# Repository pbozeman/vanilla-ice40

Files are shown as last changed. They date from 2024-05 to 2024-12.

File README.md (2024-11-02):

# Vanilla ICE40

Hardware design and verilog sample files for Lattice ICE40
development boards and expansion boards.

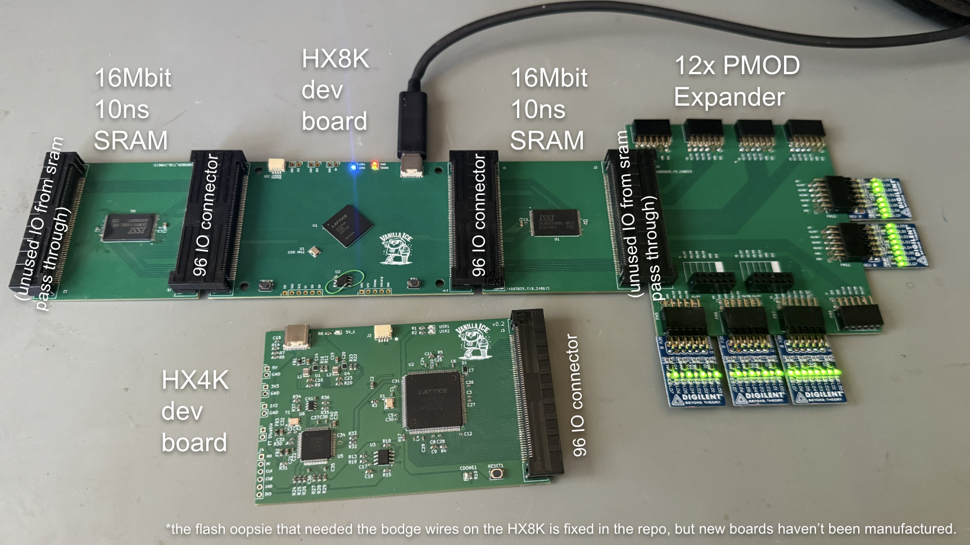
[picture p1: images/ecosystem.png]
Vanilla ICE40 ecosystem vanilla ice40 ecosystem


## Development Boards

There are 2 core boards, one based on an ICE40 HX4K with 96
available IO pins, and another based on an ICE40 HX8K with
192 available IO pins.

The core boards are "vanilla" with minimal on board peripherals.
Almost all IO pins are routed to mezzanine connectors. Expansion
boards can be mixed and matched for different projects, while reusing
the core board. The expansion boards can be daisy chained.

This is a work in progress for use in a personal project, but so far
the following boards are in the repo:

* **vanilla-ice40**: core board based on the HX4K TQ144 package. There is
an onboard USBC connector for power, programming, and uart/com port
communication. It is directly programmable with Lattice Diamond Programmer
and icestorm. The onboard FTDI chip can be disabled. The SPI pins to the
flash and ice40 are exposed if one wishes to use an external
programmer. There are 2 onboard user LEDs, 1 I2C connector, and 96 IOs
routed to a mezzanine connector on the right side of the board.

* **vanilla-ice40-hx8k**: core board based on the HX8K CT256 BGA package.
It is similar to the board above, but ads a user button on board. It has
192 available IO pins, with 96 IO pins routed to the left and 96 pins routed
to the right of the board. (A PCF file is provided for both boards, sharing
the same signal names for the right side of the board.)

* **breakout-sram**: 16Mbit sram chip with with mezzanine connectors
on both side of the board for pass through of unused pins.

* **breakout-pmod**: 12 port pmod connector, spaced such that they
can be used in single, dual or quad pmod configurations.

* **breakout-passthrough**: direct passthrough of all signals. (This
is basically a template and for testing.) NOTE: the net names and
labels on this board are stale.

Parts numbers are populated for Digikey and JLCPCB, and JLCPCB
rotations are provided. The bom and positions file, along with
gerbers, can be exported with the JLCPCB Fabrication Toolkit
plugin.

All boards other than the HX8K are single sided and optimized for cost
and hand assembly. My soldering skills are below average, and I manged to
hand assemble versions of each of these these boards other than the HX8K.
The HX8K uses BGA, via-in-pad, and 201 sized caps between the BGA pads, and
likely requires higher soldering skills.

## Verilog examples

Basic verilog examples. Icecube2 projects exist in lattice_proj.

Test benches run under iverilog by running `make check` to run
all test benches. Wave files are written
to `.build/<test_name>.vcd` and can be viewed with gtkwave.

Diamond Programmer does not use relative paths, so programmer
projects are not checked in.

### NOTE

I have been doing all recent development icestorm toolchain, so the Icecube2
projects are stale. I have heard that yosys/nextprn don't scale to larger designs,
but for now, they are able to complete synthesis and place-and-route for all
the examples before Icecube2 can synthesize a single project. That coupled with
the ability to compile and program from the command line is so delightful compared
to Icecube2.

## Makefile Targets

The Makefile in the rtl dir works for both hx4k and hx8k boards, but
one needs to change the DEVICE and PACKAGE at the top of the file based on
the board in use.

* **unit**: runs unit tests for any changed files. This is the default
target if one is not specified. vcd files are written to .build/\<name\>_tb.vcd

* **list**: provides a listing of unit test and programming targets

* **\<name\>_tb**: runs the test bench named 'name'

* **\<name\>_top**: builds the bitstream for 'name' and programs the attached board
with the bitstream.

* **lint**: runs verilator on all _tb files and their includes.

* **format**: runs verible source code formatter on all verilog files.

* **check**: runs linter and full unit test suite, even if files have not changed.

* **bits**: build bitstreams for all top level files.

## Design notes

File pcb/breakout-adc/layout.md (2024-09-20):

# Breakout ADC Layout Notes

## General notes

The board is (mostly) optimized for single sided assembly.
This is to keep costs down if using getting PCB assembly
service, or to avoid needing 2 stencils for DIY stencil based
soldering. This turned out to not be possible due to the
place and routing requirements of the op amps, but the
components on the backside were kept to a minimum and should
be easily and quickly hand soldered.

## Op Amp

[lmh6551 data sheet](https://www.ti.com/lit/ds/symlink/lmh6551.pdf)

### Power and GND plane guidelines

The following quote implies that there should be a ground plane
one layer 1 for the caps to connect directly to.

>
>The SMT capacitors should be connected directly to a ground plane.
>Thin traces or small vias will reduce the effectiveness of bypass
>capacitors.

Does this quote only apply to layer1, or does it apply to the
layers below as well?

>The LMH6551 is sensitive to parasitic capacitances on the amplifier
>inputs and to a lesser extent on the outputs as well. Ground and
>power plane metal should be removed from beneath the amplifier
>and from beneath Rf and Rg.

The 2 requirements above seem impossible to satisfy with all the
components on the top of the board. I gave up on optimizing
for single sided assembly and put the feedback network and
components on the bottom of the board. Note: the reference
design has the feedback network on the opposite side of the
chip as well.

Note: there is a power trace run under Rf, that goes under a large
percentage of the pad, but there is in the reference layout also.

## ADC

[ADC10DL065 data sheet](https://www.ti.com/lit/ds/symlink/adc10dl065.pdf)

### V reference pins

VRPA/B, VRMA/B, VMRNA/B should all share a single ground connection.
See figure 7 in the data sheet.

### DRGND

Regarding the following quote, is it ok to have a GND plane on layer 2
and then just drop a via to it as long as that via is moved a bit away
from the chip? It does seem to imply that layer1 should not have a gnd
plane around the chip and that everyone should be dropping down to the
layer below? Or, should I handle the GND for these pins as a different
net in the schematic and then run a trace away from the chip and connect
it to the main gnd with something acting as a net-tie?

>
>The ground return for the data outputs (DR GND) carries the ground current
>for the output drivers. The output current can exhibit high transients that
>could add noise to the conversion process. To prevent this from happening,
>the DR GND pins should NOT be connected to system ground in close proximity
>to any of the ADC10DL065’s other ground pins.

Confirm this was the correct routing: I ended up running the gnd vias for
DRGND outside the quiet area.

### Digital output pins
>
>The effects of the noise generated from the ADC output switching can be
>minimized through the use of 100Ω resistors in series with each data output
>line. Locate these resistors as close to the ADC output pins as possible.

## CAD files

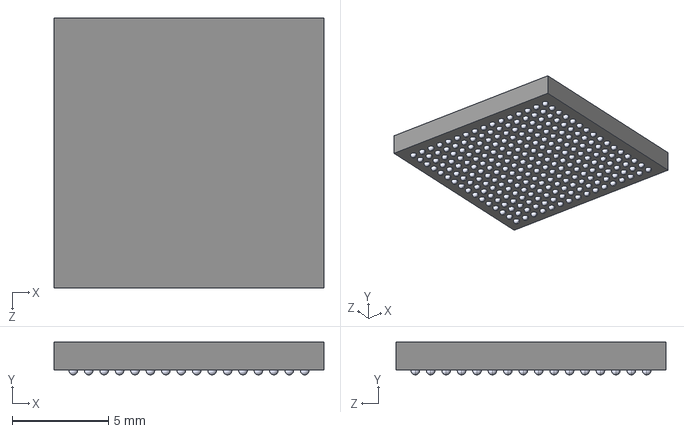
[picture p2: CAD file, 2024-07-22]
pcb/models/ICE40HX8K-CT256/ICE40HX8K-CT256.step
14.0 x 1.70 x 14.0 mm

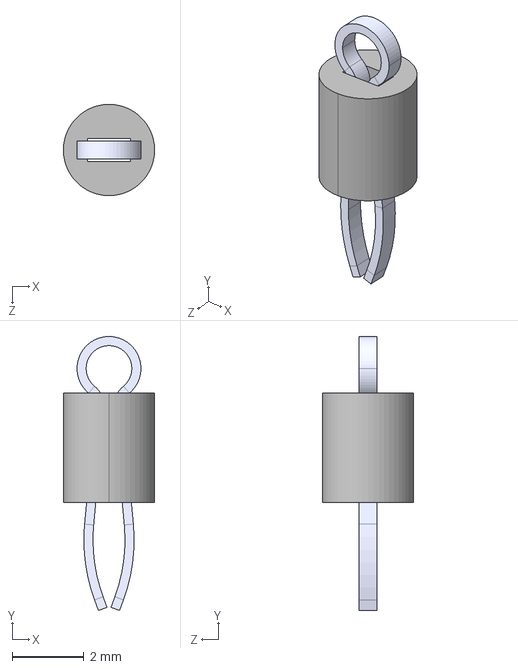
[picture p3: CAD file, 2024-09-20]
pcb/models/keystone/5118.step
2.54 x 7.62 x 2.54 mm

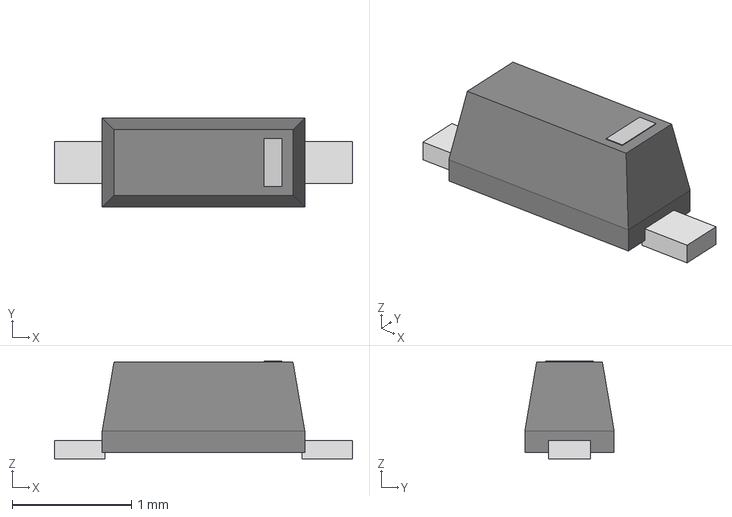
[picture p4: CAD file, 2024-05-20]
pcb/models/ul_1N4448WSF-7/SOD323F_DIO.step
2.50 x 0.75 x 0.819 mm

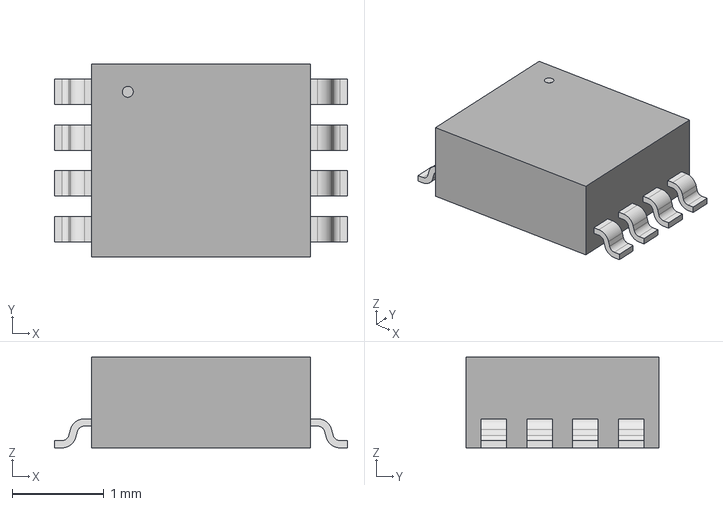
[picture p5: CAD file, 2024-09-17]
pcb/models/ul_74AVC9112DCH/VSSOP8_SOT765-1_NEX.step
3.20 x 2.11 x 0.993 mm

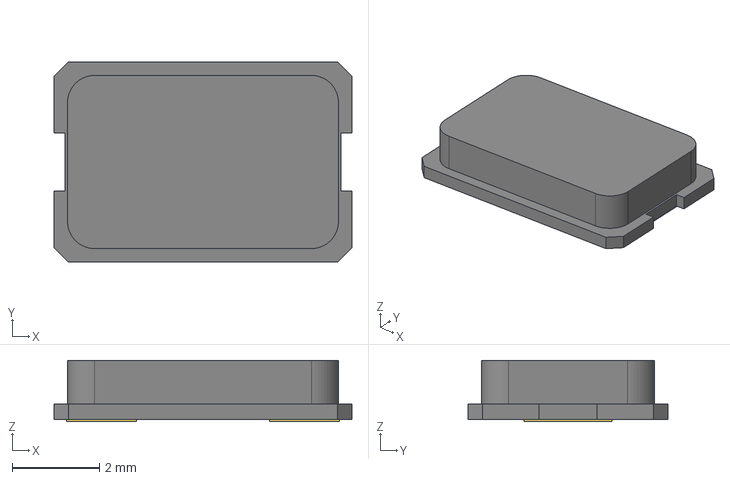
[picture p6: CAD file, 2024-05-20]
pcb/models/ul_ABM7-12-000MHZ-B4-T/XTAL_ABM7_ABR.step
6.82 x 4.58 x 1.40 mm

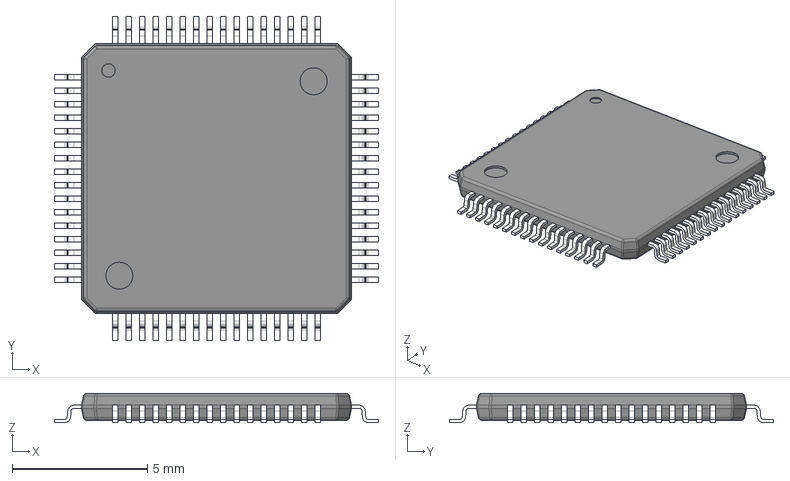
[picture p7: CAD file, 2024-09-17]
pcb/models/ul_ADC10DL065CIVS-NOPB/PAG0064A.stp
12.0 x 12.0 x 1.09 mm
BODY_VEC64A
LEAD_VEC64A x 64

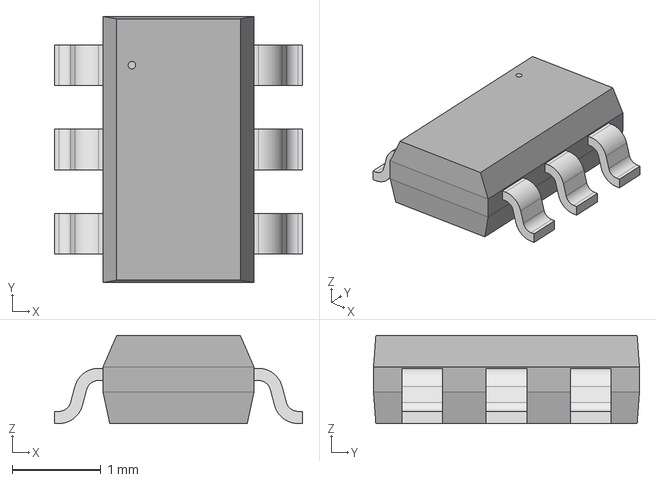
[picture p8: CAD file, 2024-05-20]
pcb/models/ul_AP63300WU-7/TSOT6_AP63300WU-7_DIO.step
2.80 x 3.00 x 0.993 mm

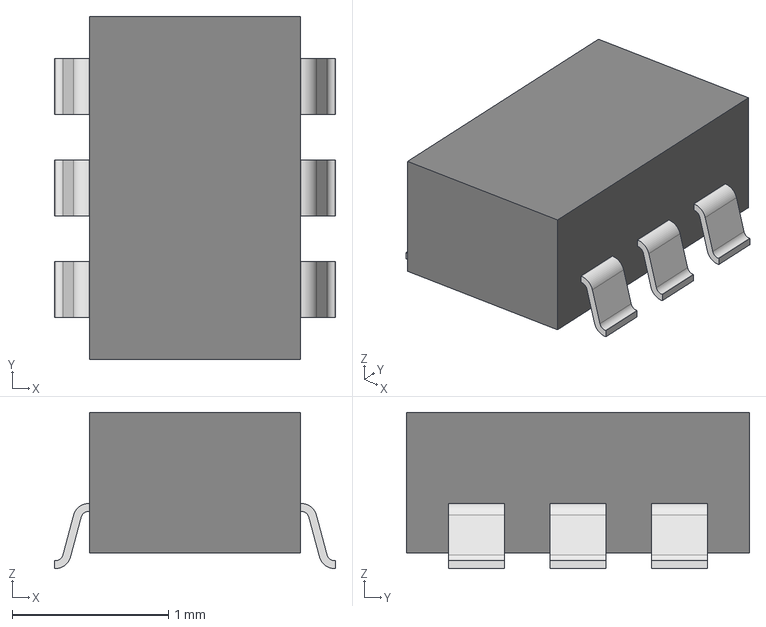
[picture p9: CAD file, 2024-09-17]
pcb/models/ul_D1213A-04S-7/SOT-363_DIO.step
1.80 x 2.20 x 1.00 mm

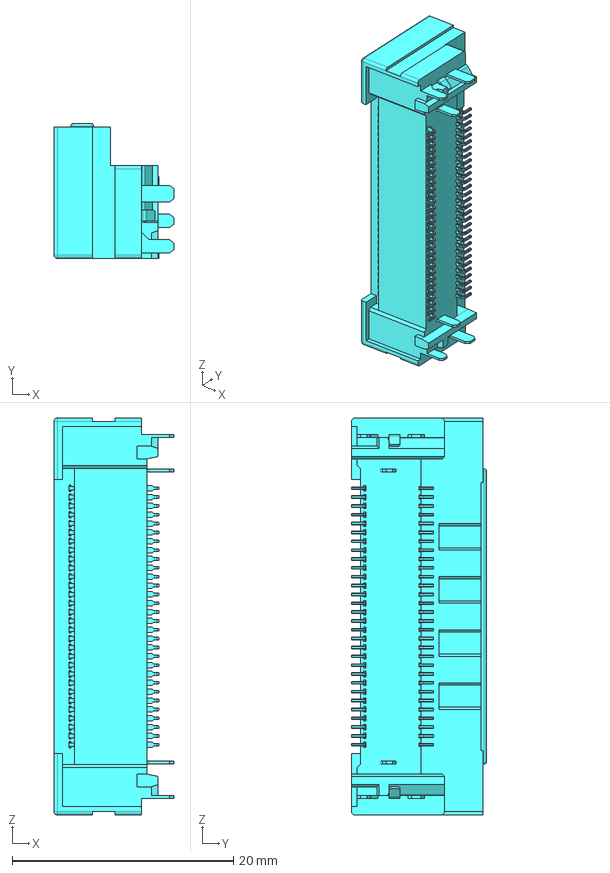
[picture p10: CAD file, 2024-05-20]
pcb/models/ul_FX18-60S-0-8SH/FX18-60S-0.8SH--3DModel-STEP-1.STEP
10.9 x 12.2 x 35.9 mm

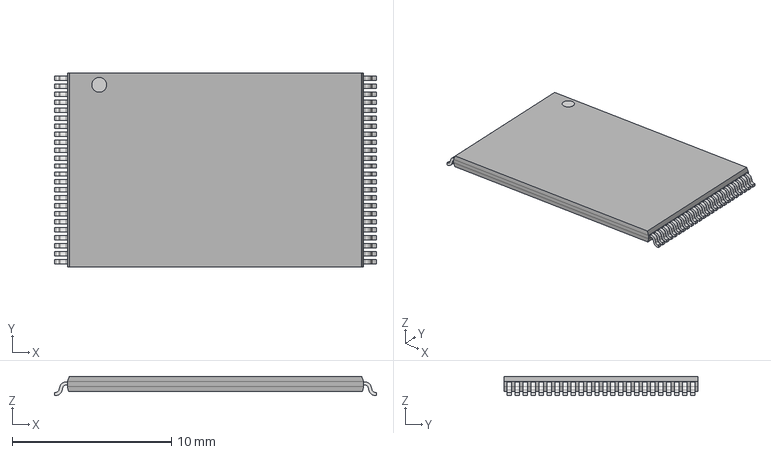
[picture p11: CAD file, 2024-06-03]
pcb/models/ul_IS61WV102416DBLL-10TLI/IS61WV102416DBLL-10TLI_ISI.step
20.2 x 12.2 x 1.20 mm

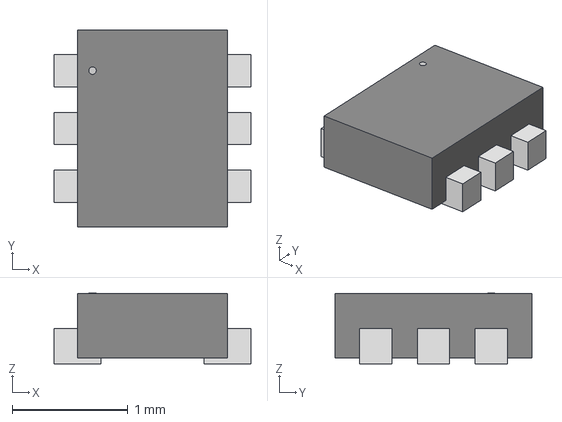
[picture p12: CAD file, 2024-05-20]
pcb/models/ul_TPS563252DRLR/SOT6_DRL_TEX.step
1.70 x 1.70 x 0.612 mm

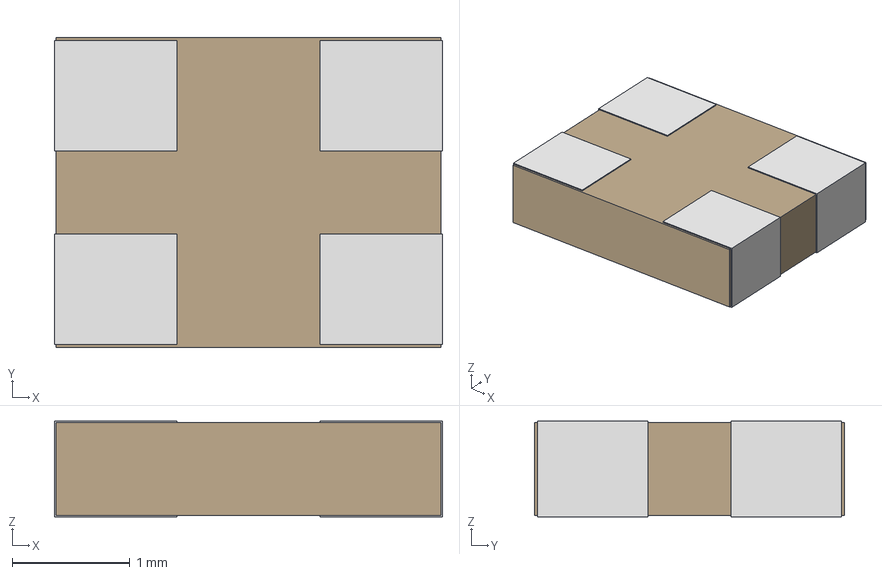
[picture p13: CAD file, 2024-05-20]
pcb/models/ul_X322512MSB4SI/SMD_2MSB4SI_YXC.step
3.30 x 2.64 x 0.813 mm

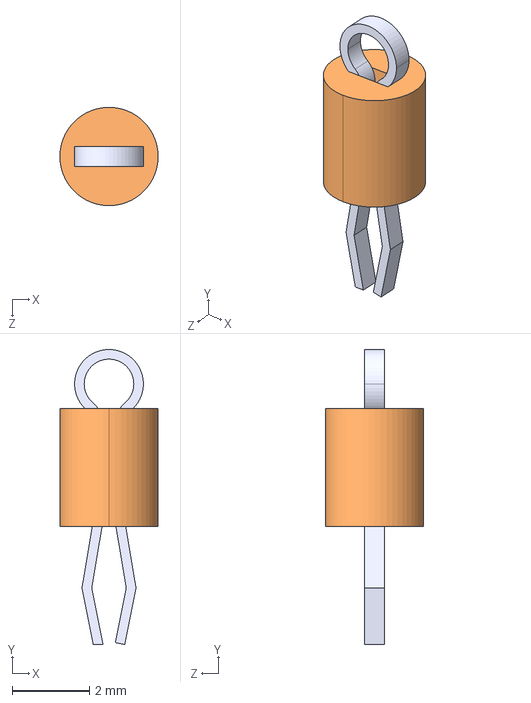
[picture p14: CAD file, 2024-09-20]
pcb/models/keystone/5003.step
2.54 x 7.62 x 2.54 mm

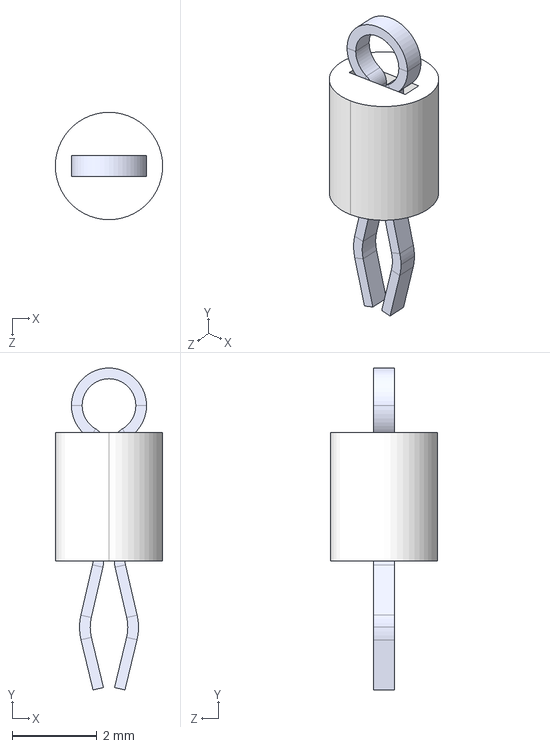
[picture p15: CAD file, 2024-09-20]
pcb/models/keystone/5002.step
2.54 x 7.62 x 2.54 mm

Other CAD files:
pcb/models/keystone/5001.step
pcb/models/keystone/5115.step
pcb/models/keystone/5116.step
pcb/models/keystone/5117.step
pcb/models/keystone/5000.step
pcb/models/keystone/5004.step
pcb/models/keystone/5119.step

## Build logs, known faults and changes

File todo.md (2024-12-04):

# Todo and fixes

## PCB

### All

- consider redoing the pins on the P b2b connector to match S.
- audit and standardize R manufacturer. Used to be bournes,
  but the need for 0.1% tolerance from the same vendor at both
  digikey and lcsc meant using Yaego. (Not that multivendor is
  bad, but I find single vendor to be more ascetically pleasing :)

### Main board

- lcsc green led is a bit dim
- validate i2c
- validate urx/utx
- validate all passive silk screen positions
- bump font sizes
- remove 3v3 and 1v2 voltage breakouts
- consider signal only option to use ice boards together
- should OE enable on the oscillator use a 1K+ resistor instead of 0R?
- move the resistors for the LEDs to the top of the board. They made good
  test points, and testing at the led doesn't work as well.

### ADC board

- X1 is a default kicad symbol and footprint. I added a pin 1 marker, but
  accidentally did so to the system footprint. Duplicate the symbol as a custom
  symbol and fix the datasheet and footprint correctly.

### PMOD board

- make font bigger
- move pmods slightly over the edge of the pcb
- add mounting holes

### Pass through

- update with current board tolerances and sizes (e.g. vias are off)

### SRAM

- add mounting holes
- lower pcb fence vias violate drc tolerances

## RTL

### Project structure

- start moving modules into groups directories in lib
- move unit tests with the lib
- add some sort of check for required parameters to ensure they are set.
  Removing defaults is not an option because icecube2 requires them.

### make

- make: all files are included in both yosys and verification.. limit them to just
  the dependencies
- move to per top pcf files
- there are some assumptions of running from the rtl/examples dir, e.g.
  the pcf gen rules. update the makefile to be cwd agnostic
- consider removing pcf files from being committed to the repo

### misc

- make sure all components have a reset_i
- create reset component and use in top modules

### uart

- add tests

### SRAM

change the sram data and addr ports to use _bus and/or differentiate the caller ports from the
io on the board

### SRAM VGA

- don't read memory during the blanking period
- use vga_pixel_addr, or at least the counter module. There was a wrapping
  error in the manual iteration that wouldn't have happened if these were used.

### axi

- add a tb for axi_sram_dbuf_controller
- data signals are not always multiple of 8 bit values in these designs. Decide if
  this is an issue or not.
- rename axi modules to bla_axi instead of axi_bla, with the exception of modules
  that specifically do axi managment like the axi_2x2
- use the tnx_done detector to track handshakes, especially when needing to
  combine A and W which may not happen at the same time

### adc vga

- use double buffering. Even 800x600 doesn't work with a single sram because
it's running at a 40mhz pixel clock and is trying to share an sram module that
takes 2 clocks per op to complete due to setup and hold times. That means we
are effectively writting/reading at 50mhz. When there is a reader and writer both contending for the sram, the bw of both is reduce to 25mhz, making 640x480 the
max we can do. Double buffering will bring this up to 50mhz, which is enough
for 800x600's 40mhz. 1024x768 will need pipelining/interleaving on top of this.

### gfx

- use axi like interface with valid/ready inputs and valid/ready/last outputs

### Style

- move to system verilog, but decide on what conventions to use
- rename _controller to_ctrl
- use initial_reset in top modules
- use TICK in unit tests
- use ASSERT_EQ in unit tests where applicable
- switch to axi stream for flow control in relevant modules
- move to standardized module instantiation names
- decide on standardize _WIDTH/BITS parameter names
- there is a mix of usage of state, current_state. pick one
- pick if next_ goes at the front or the end
- put _io_ in the port names of wires on the board
- use .signal() for unused signals

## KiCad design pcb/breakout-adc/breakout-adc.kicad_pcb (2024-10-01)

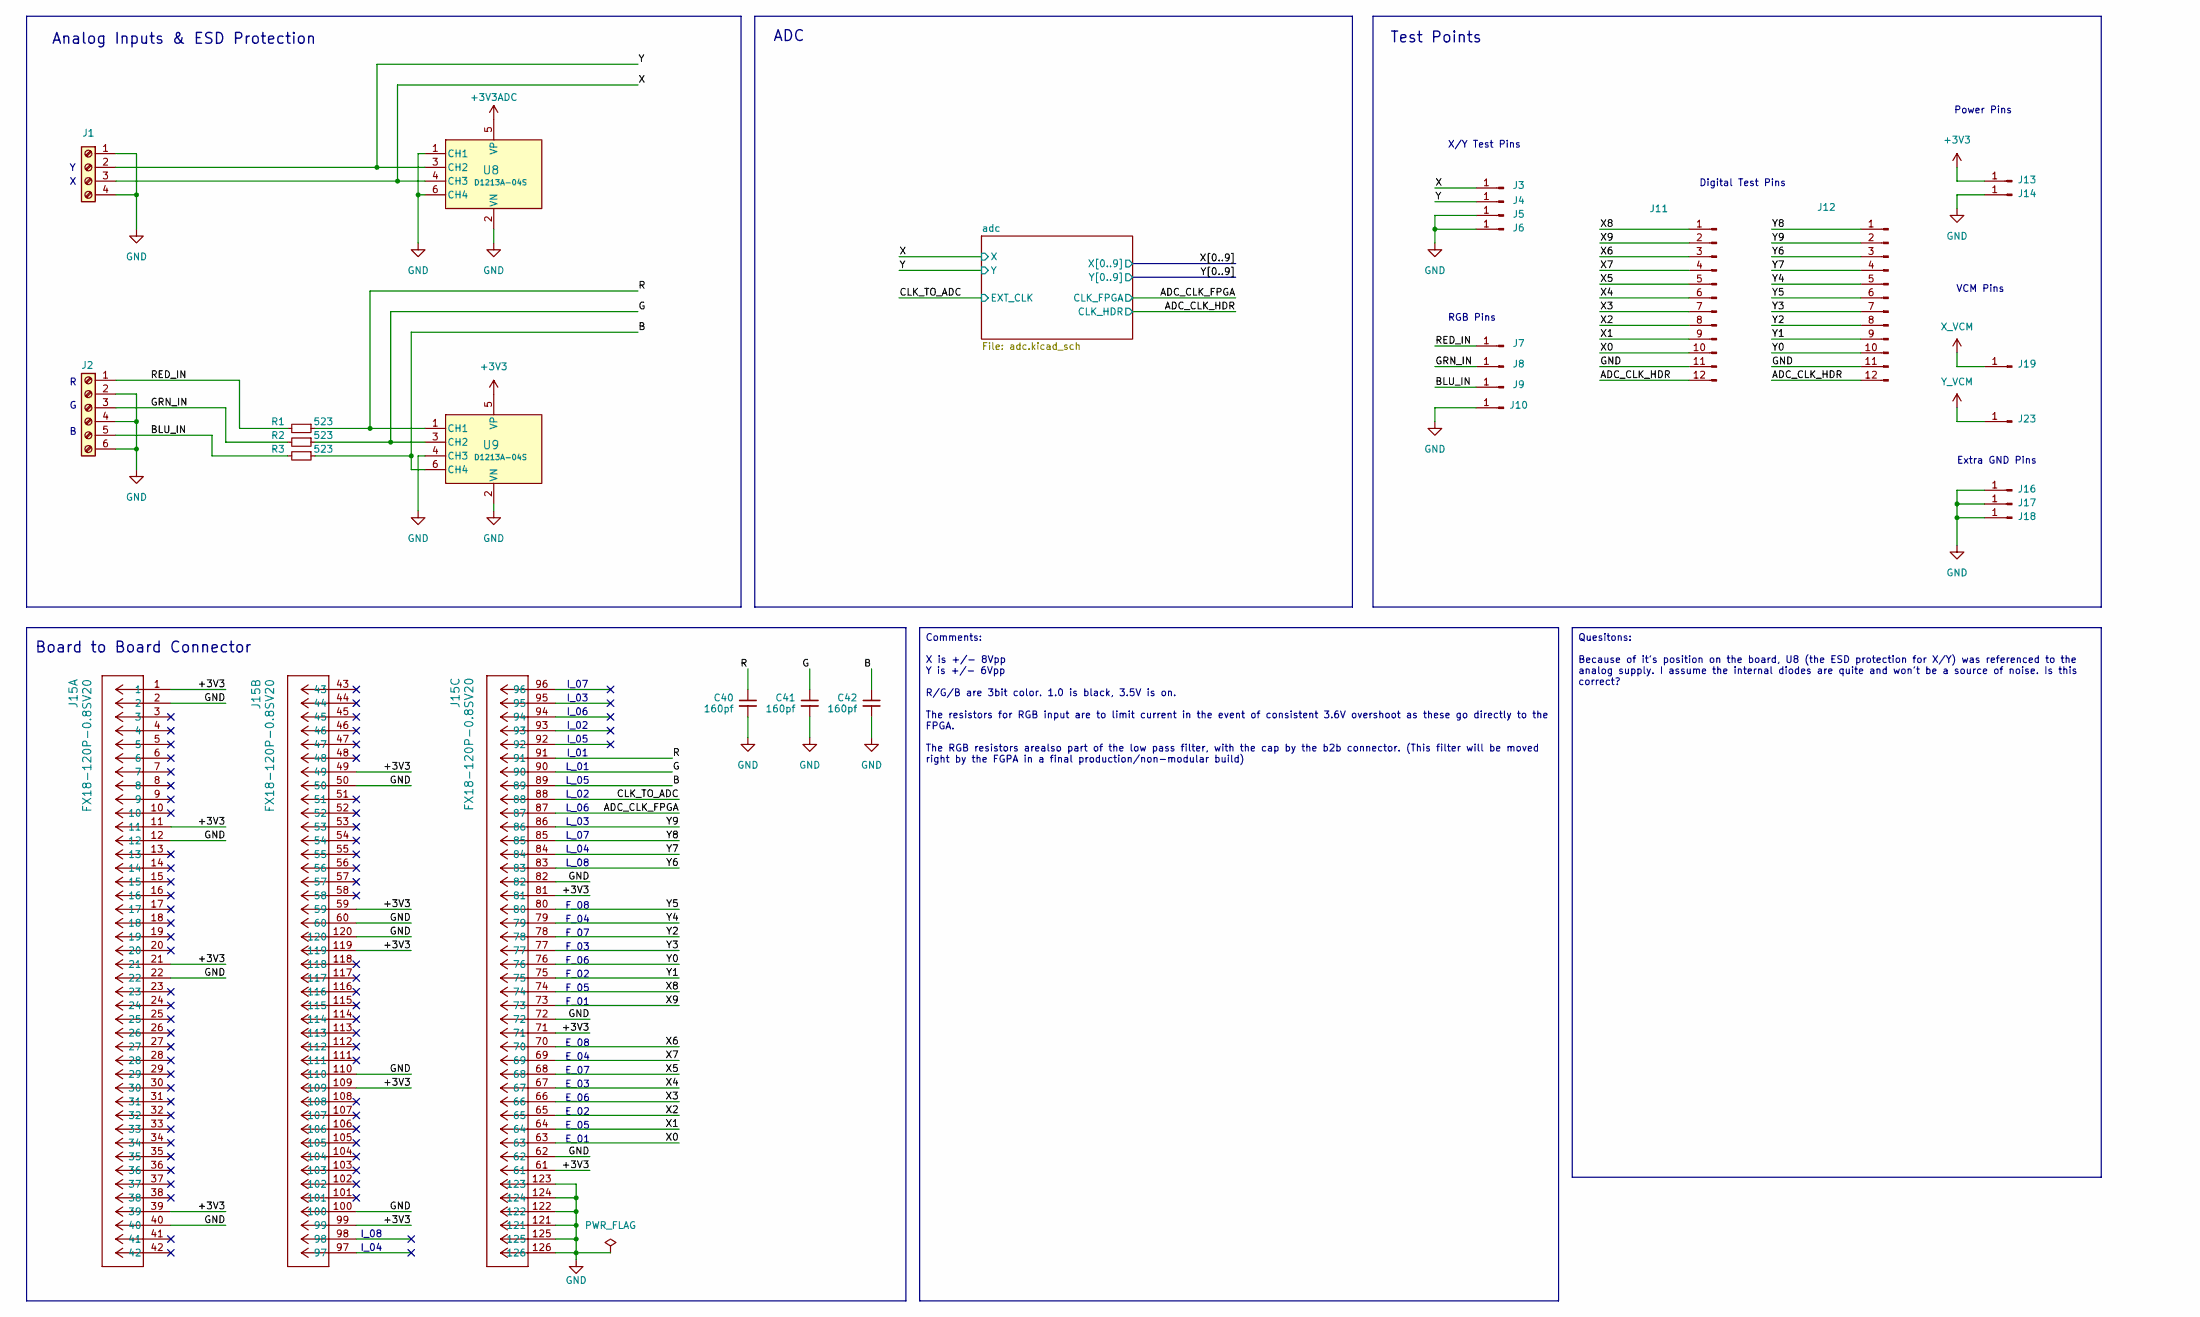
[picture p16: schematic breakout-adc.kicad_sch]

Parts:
C40, C41, C42: 160pf; C_0402_1005Metric; Digi-Key Part Number 490-GRT1555C1H161FA02DCT-ND
J1: Screw_Terminal_01x04; PhoenixContact_MC_1,5_4-G-3.81_1x04_P3.81mm_Horizontal; Digi-Key Part Number 277-1208-ND
J2: Screw_Terminal_01x06; PhoenixContact_MC_1,5_6-G-3.81_1x06_P3.81mm_Horizontal; Digi-Key Part Number 277-1210-ND
J3, J4: White; KEYSTONE_5002; Digi-Key Part Number 36-5002-ND
J5, J6, J10, J14, J16, J17, J18: Black; KEYSTONE_5001; Digi-Key Part Number 36-5001-ND
J7, J13: Red; KEYSTONE_5000; Digi-Key Part Number 36-5000-ND
J8: Green; KEYSTONE_5116; Digi-Key Part Number 36-5116-ND
J9, J19, J23: Blue; KEYSTONE_5117; Digi-Key Part Number 36-5117-ND
J11, J12: Conn_02x06_Pin; PinHeader_2x06_P2.54mm_Vertical; Digi-Key Part Number 952-2125-ND
J15: FX18-120P-0.8SV20; CUSTOM_FX_120P-0.8SH20; Digi-Key Part Number H11865-ND
R1, R2, R3: 523; R_0805_2012Metric; LCSC Part # C227952
U8, U9: D1213A-04S; SOT-363_DIO; Digi-Key Part Number D1213A-04S-7DICT-ND

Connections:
+3V3: J13.1, J15.1, J15.11, J15.21, J15.39, J15.49, J15.59, J15.61, J15.71, J15.81, J15.99, J15.109, J15.119, U9.5 (VP); also elsewhere on the board
+3V3ADC: U8.5 (VP); also elsewhere on the board
/ADC_CLK_FPGA: J15.87; also elsewhere on the board
/ADC_CLK_HDR: J11.12, J12.12; also elsewhere on the board
/B: C42.1, J15.89, R3.1, U9.6 (CH4)
/BLU_IN: J2.5, J9.1, R3.2
/CLK_TO_ADC: J15.88; also elsewhere on the board
/G: C41.1, J15.90, R2.1, U9.3 (CH2)
/GRN_IN: J2.3, J8.1, R2.2
/R: C40.1, J15.91, R1.1, U9.1 (CH1)
/RED_IN: J2.1, J7.1, R1.2
/X: J1.3, J3.1, U8.4 (CH3); also elsewhere on the board
/X0: J11.10, J15.63; also elsewhere on the board
/X1: J11.9, J15.64; also elsewhere on the board
/X2: J11.8, J15.65; also elsewhere on the board
/X3: J11.7, J15.66; also elsewhere on the board
/X4: J11.6, J15.67; also elsewhere on the board
/X5: J11.5, J15.68; also elsewhere on the board
/X6: J11.3, J15.70; also elsewhere on the board
/X7: J11.4, J15.69; also elsewhere on the board
/X8: J11.1, J15.74; also elsewhere on the board
/X9: J11.2, J15.73; also elsewhere on the board
/Y: J1.2, J4.1, U8.3 (CH2); also elsewhere on the board
/Y0: J12.10, J15.76; also elsewhere on the board
/Y1: J12.9, J15.75; also elsewhere on the board
/Y2: J12.8, J15.78; also elsewhere on the board
/Y3: J12.7, J15.77; also elsewhere on the board
/Y4: J12.5, J15.79; also elsewhere on the board
/Y5: J12.6, J15.80; also elsewhere on the board
/Y6: J12.3, J15.83; also elsewhere on the board
/Y7: J12.4, J15.84; also elsewhere on the board
/Y8: J12.1, J15.85; also elsewhere on the board
/Y9: J12.2, J15.86; also elsewhere on the board
GND: C40.2, C41.2, C42.2, J1.1, J1.4, J2.2, J2.4, J2.6, J5.1, J6.1, J10.1, J11.11, J12.11, J14.1, J15.2, J15.12, J15.22, J15.40, J15.50, J15.60, J15.62, J15.72, J15.82, J15.100, J15.110, J15.120, J15.121, J15.122, J15.123, J15.124, J15.125, J15.126, J16.1, J17.1, J18.1, U8.1 (CH1), U8.2 (VN), U8.6 (CH4), U9.2 (VN), U9.4 (CH3); also elsewhere on the board
X_VCM: J19.1; also elsewhere on the board
Y_VCM: J23.1; also elsewhere on the board

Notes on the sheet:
Comments: X is +/- 8Vpp Y is +/- 6Vpp R/G/B are 3bit color. 1.0 is black, 3.5V is on. The resistors for RGB input are to limit current in the event of consistent 3.6V overshoot as these go directly to the FPGA. The RGB resistors arealso part of the low pass filter, with the cap by the b2b connector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
Quesitons: Because of it's position on the board, U8 (the ESD protection for X/Y) was referenced to the analog supply. I assume the internal diodes are quite and won't be a source of noise. Is this correct?
Power Pins
Test Points
E_07
VCM Pins
L_04
Extra GND Pins
L_03
I_02
E_08
I_04
L_01
E_01
I_06
L_06
E_02
Board to Board Connector
E_06
L_08
Analog Inputs & ESD Protection
Digital Test Pins
F_02
L_05
F_04
E_04
X/Y Test Pins
RGB Pins
E_05
F_08
F_06
F_01
ADC
I_01
L_02
F_07
I_05
I_07
E_03
F_03

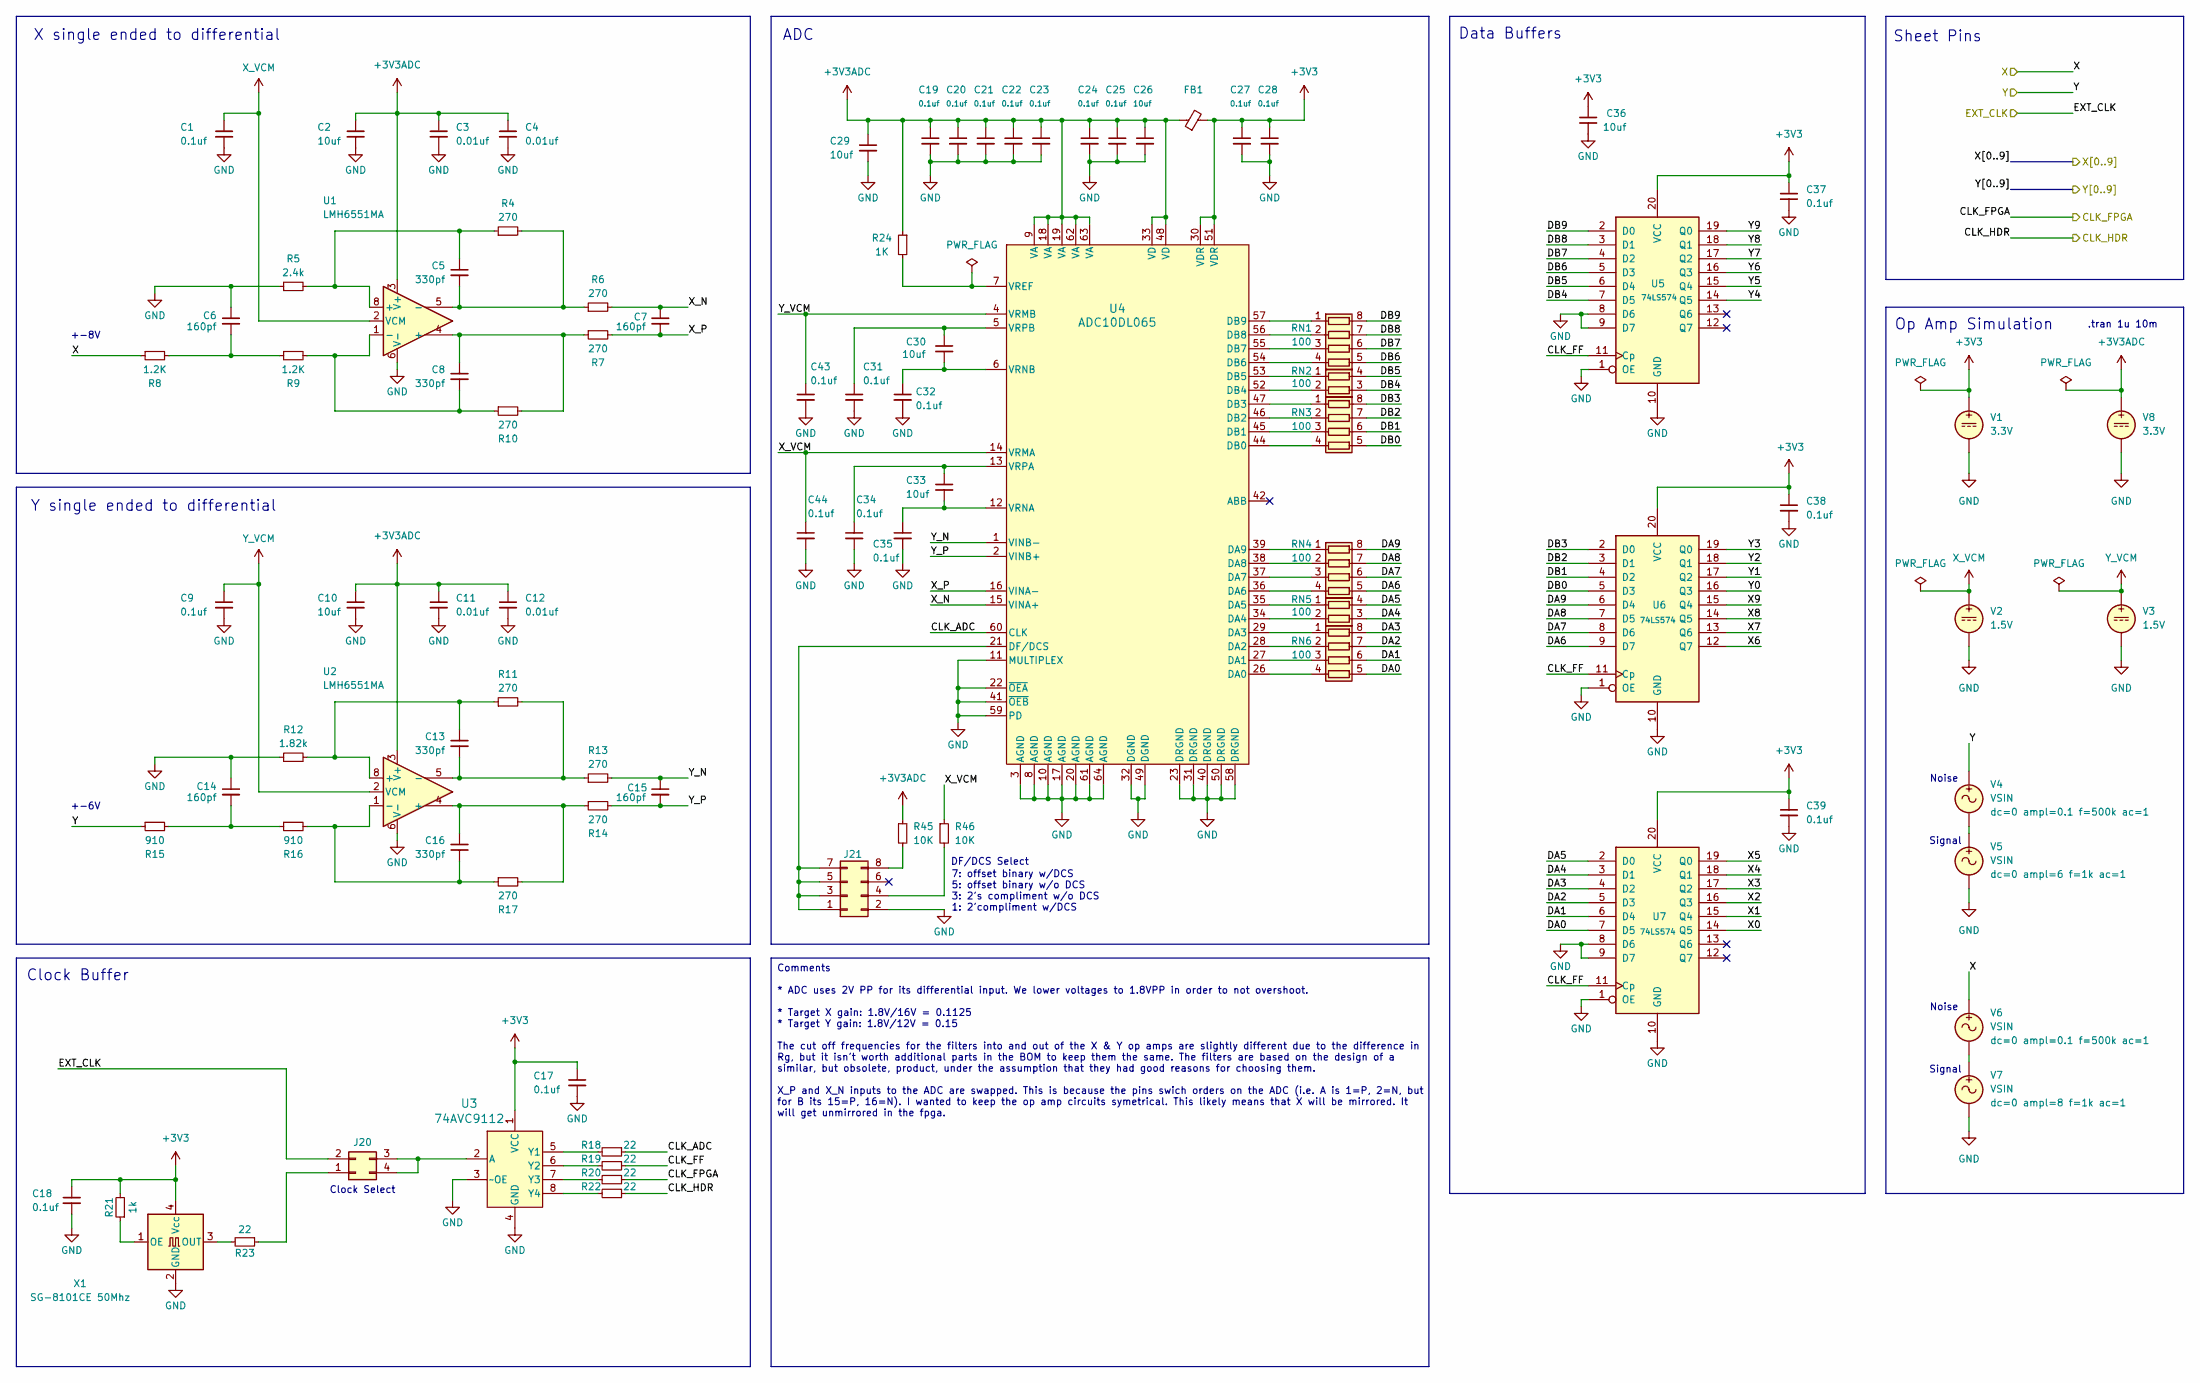
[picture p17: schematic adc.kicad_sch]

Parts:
C1, C9, C17, C18, C19, C20, C21, C22, C23, C24, C25, C27, C28, C31, C32, C34, C35, C37, C38, C39, C43, C44: 0.1uf; C_0402_1005Metric; LCSC Part # C71629
C2, C10, C26, C29, C30, C33, C36: 10uf; C_0603_1608Metric; LCSC Part # C77041
C3, C4, C11, C12: 0.01uf; C_0402_1005Metric; LCSC Part # C85735
C5, C8, C13, C16: 330pf; C_0402_1005Metric; Digi-Key Part Number 490-3247-1-ND
C6, C7, C14, C15: 160pf; C_0402_1005Metric; Digi-Key Part Number 490-GRT1555C1H161FA02DCT-ND
FB1: L_0603_1608Metric; LCSC Part # C1002
J20: Conn_02x02_Counter_Clockwise; PinHeader_2x02_P2.54mm_Vertical; Digi-Key Part Number 952-2119-ND
J21: Conn_02x04_Odd_Even; PinHeader_2x04_P2.54mm_Vertical; Digi-Key Part Number 952-2122-ND
R4, R6, R7, R10, R11, R13, R14, R17: 270; R_0603_1608Metric; Digi-Key Part Number YAG1606CT-ND
R5: 2.4k; R_0603_1608Metric; Digi-Key Part Number YAG1619CT-ND
R8, R9: 1.2K; R_0603_1608Metric; Digi-Key Part Number YAG1563CT-ND
R12: 1.82k; R_0603_1608Metric; Digi-Key Part Number YAG1575CT-ND
R15, R16: 910; R_0603_1608Metric; Digi-Key Part Number YAG1748CT-ND
R18, R19, R20, R22, R23: 22; R_0603_1608Metric; LCSC Part # C107701
R21: 1k; R_0603_1608Metric; LCSC Part # C22548
R24: 1K; R_0603_1608Metric; Digi-Key Part Number 311-1.00KHRCT-ND
R45, R46: 10K; R_0603_1608Metric; Digi-Key Part Number 311-10.0KHRCT-ND
RN1, RN3, RN4, RN6: 100; R_Array_Concave_4x0402; LCSC Part # C326873
RN2, RN5: 100; R_Array_Convex_2x0402; Digi-Key Part Number 13-YC122-FR-07100RLCT-ND
U1, U2: LMH6551MA; SOIC-8_3.9x4.9mm_P1.27mm; Digi-Key Part Number LMH6551MA/NOPB-ND
U3: 74AVC9112; VSSOP8_SOT765-1_NEX; Digi-Key Part Number 1727-7845-1-ND
U4: ADC10DL065; VEC64A_TEX; Digi-Key Part Number ADC10DL065CIVS/NOPB-ND
U5, U6, U7: 74LS574; TSSOP-20_4.4x6.5mm_P0.65mm; Digi-Key Part Number 296-8532-1-ND
V1, V8: 3.3V
V2, V3: 1.5V
V4, V5, V6, V7: VSIN
X1: SG-8101CE 50Mhz; Oscillator_SMD_SeikoEpson_SG8002CE-4Pin_3.2x2.5mm; LCSC Part # C390556

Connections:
+3V3: C17.1, C18.1, C27.1, C28.1, C36.1, C37.1, C38.1, C39.1, FB1.2, R21.2, U3.1 (VCC), U4.30 (VDR), U4.51 (VDR), U5.20 (VCC), U6.20 (VCC), U7.20 (VCC), V1.1, X1.4 (Vcc); also elsewhere on the board
+3V3ADC: C2.1, C3.1, C4.1, C10.1, C11.1, C12.1, C19.1, C20.1, C21.1, C22.1, C23.1, C24.1, C25.1, C26.1, C29.1, FB1.1, R24.1, R45.1, U1.3 (V+), U2.3 (V+), U4.9 (VA), U4.18 (VA), U4.19 (VA), U4.33 (VD), U4.48 (VD), U4.62 (VA), U4.63 (VA), V8.1; also elsewhere on the board
/ADC_CLK_FPGA: R20.1; also elsewhere on the board
/ADC_CLK_HDR: R22.1; also elsewhere on the board
/CLK_TO_ADC: J20.2; also elsewhere on the board
/X: R8.1, V6.1; also elsewhere on the board
/X0: U7.14 (Q5); also elsewhere on the board
/X1: U7.15 (Q4); also elsewhere on the board
/X2: U7.16 (Q3); also elsewhere on the board
/X3: U7.17 (Q2); also elsewhere on the board
/X4: U7.18 (Q1); also elsewhere on the board
/X5: U7.19 (Q0); also elsewhere on the board
/X6: U6.12 (Q7); also elsewhere on the board
/X7: U6.13 (Q6); also elsewhere on the board
/X8: U6.14 (Q5); also elsewhere on the board
/X9: U6.15 (Q4); also elsewhere on the board
/Y: R15.1, V4.1; also elsewhere on the board
/Y0: U6.16 (Q3); also elsewhere on the board
/Y1: U6.17 (Q2); also elsewhere on the board
/Y2: U6.18 (Q1); also elsewhere on the board
/Y3: U6.19 (Q0); also elsewhere on the board
/Y4: U5.14 (Q5); also elsewhere on the board
/Y5: U5.15 (Q4); also elsewhere on the board
/Y6: U5.16 (Q3); also elsewhere on the board
/Y7: U5.17 (Q2); also elsewhere on the board
/Y8: U5.18 (Q1); also elsewhere on the board
/Y9: U5.19 (Q0); also elsewhere on the board
/adc/CLK_ADC: R18.1, U4.60 (CLK)
/adc/CLK_FF: R19.1, U5.11 (Cp), U6.11 (Cp), U7.11 (Cp)
/adc/DA0: RN6.5 (R4.2), U7.7 (D5)
/adc/DA1: RN6.6 (R3.2), U7.6 (D4)
/adc/DA2: RN6.7 (R2.2), U7.5 (D3)
/adc/DA3: RN6.8 (R1.2), U7.4 (D2)
/adc/DA4: RN5.3 (R2.2), U7.3 (D1)
/adc/DA5: RN5.4 (R1.2), U7.2 (D0)
/adc/DA6: RN4.5 (R4.2), U6.9 (D7)
/adc/DA7: RN4.6 (R3.2), U6.8 (D6)
/adc/DA8: RN4.7 (R2.2), U6.7 (D5)
/adc/DA9: RN4.8 (R1.2), U6.6 (D4)
/adc/DB0: RN3.5 (R4.2), U6.5 (D3)
/adc/DB1: RN3.6 (R3.2), U6.4 (D2)
/adc/DB2: RN3.7 (R2.2), U6.3 (D1)
/adc/DB3: RN3.8 (R1.2), U6.2 (D0)
/adc/DB4: RN2.3 (R2.2), U5.7 (D5)
/adc/DB5: RN2.4 (R1.2), U5.6 (D4)
/adc/DB6: RN1.5 (R4.2), U5.5 (D3)
/adc/DB7: RN1.6 (R3.2), U5.4 (D2)
/adc/DB8: RN1.7 (R2.2), U5.3 (D1)
/adc/DB9: RN1.8 (R1.2), U5.2 (D0)
/adc/X_N: C7.1, R6.2, U4.15 (VINA+)
/adc/X_P: C7.2, R7.2, U4.16 (VINA-)
/adc/Y_N: C15.1, R13.2, U4.1 (VINB-)
/adc/Y_P: C15.2, R14.2, U4.2 (VINB+)
GND: C1.2, C2.2, C3.2, C4.2, C6.1, C9.2, C10.2, C11.2, C12.2, C14.1, C17.2, C18.2, C19.2, C20.2, C21.2, C22.2, C23.2, C24.2, C25.2, C26.2, C27.2, C28.2, C29.2, C31.2, C32.2, C34.2, C35.2, C36.2, C37.2, C38.2, C39.2, C43.2, C44.2, J21.2, R5.1, R12.1, U1.6 (V-), U2.6 (V-), U3.3 (~OE), U3.4 (GND), U4.3 (AGND), U4.8 (AGND), U4.10 (AGND), U4.11 (MULTIPLEX), U4.17 (AGND), U4.20 (AGND), U4.22 (~OEA), U4.23 (DRGND), U4.31 (DRGND), U4.32 (DGND), U4.40 (DRGND), U4.41 (~OEB), U4.49 (DGND), U4.50 (DRGND), U4.58 (DRGND), U4.59 (PD), U4.61 (AGND), U4.64 (AGND), U5.1 (OE), U5.8 (D6), U5.9 (D7), U5.10 (GND), U6.1 (OE), U6.10 (GND), U7.1 (OE), U7.8 (D6), U7.9 (D7), U7.10 (GND), V1.2, V2.2, V3.2, V5.2, V7.2, V8.2, X1.2 (GND); also elsewhere on the board
unnamed: C5.1, R4.1, R5.2, U1.8 (+)
unnamed: C5.2, R4.2, R6.1, U1.5 (-)
unnamed: C6.2, R8.2, R9.1
unnamed: C8.1, R7.1, R10.2, U1.4 (+)
unnamed: C8.2, R9.2, R10.1, U1.1 (-)
unnamed: C13.1, R11.1, R12.2, U2.8 (+)
unnamed: C13.2, R11.2, R13.1, U2.5 (-)
unnamed: C14.2, R15.2, R16.1
unnamed: C16.1, R14.1, R17.2, U2.4 (+)
unnamed: C16.2, R16.2, R17.1, U2.1 (-)
unnamed: J20.1, R23.1
unnamed: J20.3, J20.4, U3.2 (A)
unnamed: J21.1, J21.3, J21.5, J21.7, U4.21 (DF/DCS)
unnamed: J21.4, R46.2
unnamed: J21.8, R45.2
unnamed: RN1.1 (R1.1), U4.57 (DB9)
unnamed: RN1.2 (R2.1), U4.56 (DB8)
unnamed: RN1.3 (R3.1), U4.55 (DB7)
unnamed: RN1.4 (R4.1), U4.54 (DB6)
unnamed: RN2.1 (R1.1), U4.53 (DB5)
unnamed: RN2.2 (R2.1), U4.52 (DB4)
unnamed: RN3.1 (R1.1), U4.47 (DB3)
unnamed: RN3.2 (R2.1), U4.46 (DB2)
unnamed: RN3.3 (R3.1), U4.45 (DB1)
unnamed: RN3.4 (R4.1), U4.44 (DB0)
unnamed: RN4.1 (R1.1), U4.39 (DA9)
unnamed: RN4.2 (R2.1), U4.38 (DA8)
unnamed: RN4.3 (R3.1), U4.37 (DA7)
unnamed: RN4.4 (R4.1), U4.36 (DA6)
unnamed: RN5.1 (R1.1), U4.35 (DA5)
unnamed: RN5.2 (R2.1), U4.34 (DA4)
unnamed: RN6.1 (R1.1), U4.29 (DA3)
unnamed: RN6.2 (R2.1), U4.28 (DA2)
unnamed: RN6.3 (R3.1), U4.27 (DA1)
unnamed: RN6.4 (R4.1), U4.26 (DA0)
unnamed: R18.2, U3.5 (Y1)
unnamed: R19.2, U3.6 (Y2)
unnamed: R20.2, U3.7 (Y3)
unnamed: R22.2, U3.8 (Y4)
unnamed: R24.2, U4.7 (VREF)
unnamed: C33.2, C35.1, U4.12 (VRNA)
unnamed: C30.2, C32.1, U4.6 (VRNB)
unnamed: C33.1, C34.1, U4.13 (VRPA)
unnamed: C30.1, C31.1, U4.5 (VRPB)
unnamed: V4.2, V5.1
unnamed: V6.2, V7.1
unnamed: R21.1, X1.1 (OE)
unnamed: R23.2, X1.3 (OUT)
X_VCM: C1.1, C44.1, R46.1, U1.2 (VCM), U4.14 (VRMA), V2.1; also elsewhere on the board
Y_VCM: C9.1, C43.1, U2.2 (VCM), U4.4 (VRMB), V3.1; also elsewhere on the board

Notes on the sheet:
Comments * ADC uses 2V PP for its differential input. We lower voltages to 1.8VPP in order to not overshoot. * Target X gain: 1.8V/16V = 0.1125 * Target Y gain: 1.8V/12V = 0.15 The cut off frequencies for the filters into and out of the X & Y op amps are slightly different due to the difference in 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
Y single ended to differential
7: offset binary w/DCS 5: offset binary w/o DCS 3: 2's compliment w/o DCS 1: 2'compliment w/DCS
+-8V
Signal
Data Buffers
Clock Select
.tran 1u 10m
X single ended to differential
Noise
ADC
Sheet Pins
Op Amp Simulation
+-6V
DF/DCS Select
Clock Buffer

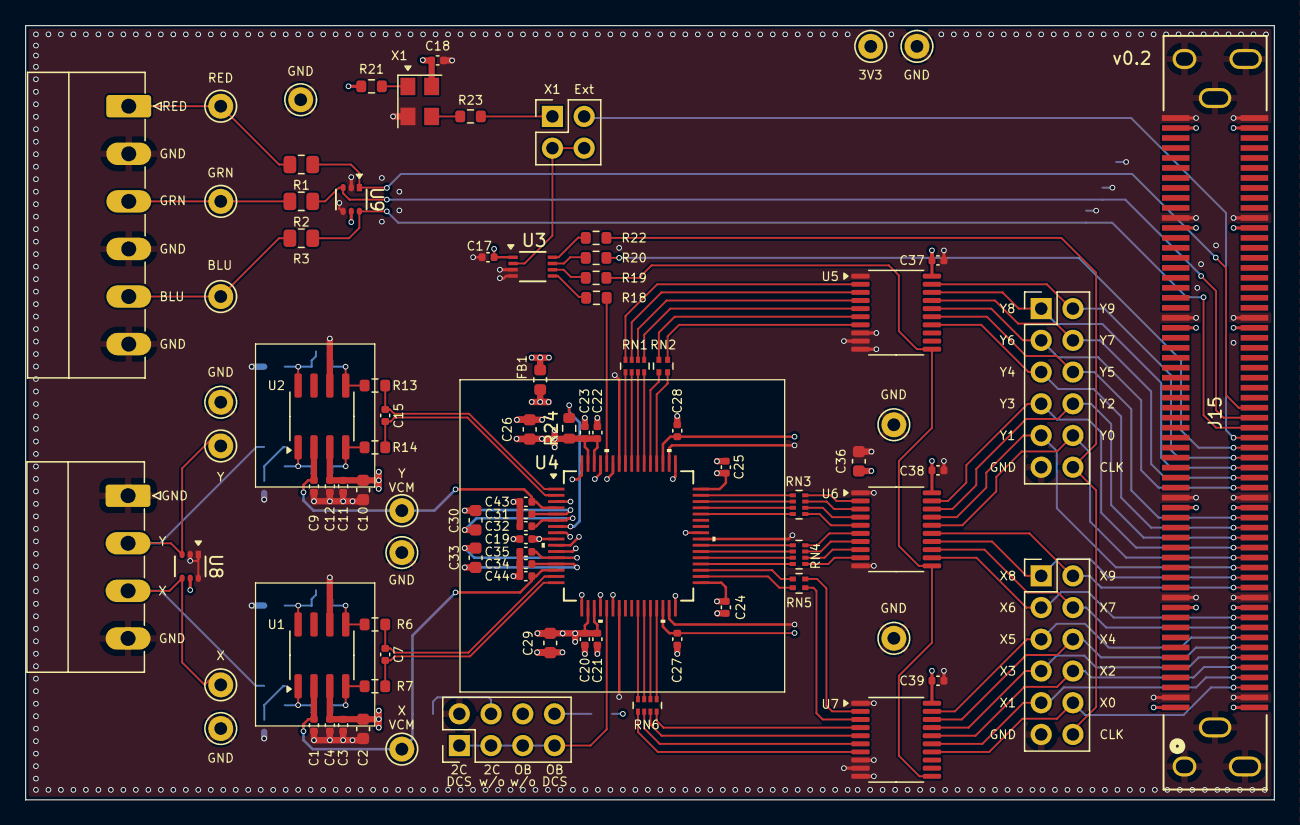
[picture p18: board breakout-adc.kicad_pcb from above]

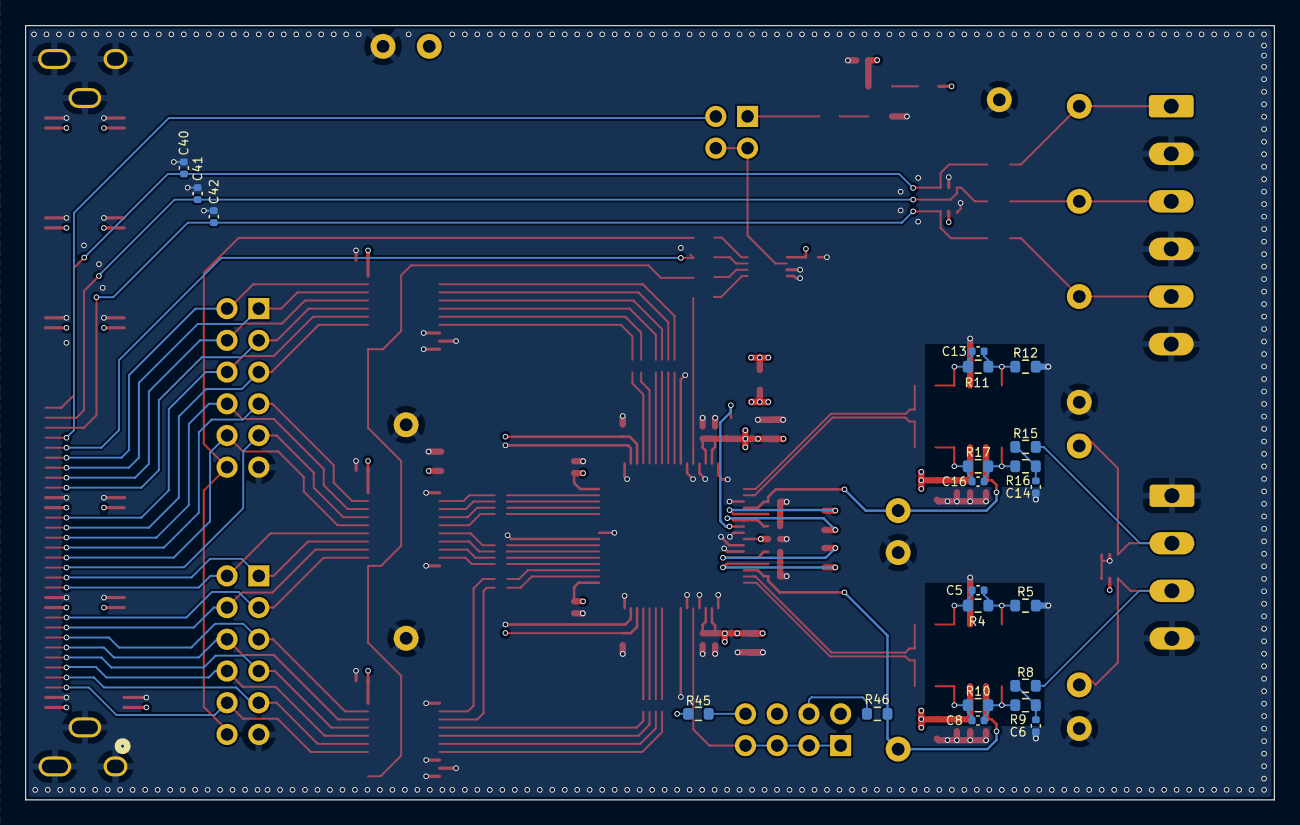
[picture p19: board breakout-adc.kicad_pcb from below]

Board: 4 copper layers, 100.0 x 62.0 mm, 109 parts (21 on the bottom side), 108 nets.

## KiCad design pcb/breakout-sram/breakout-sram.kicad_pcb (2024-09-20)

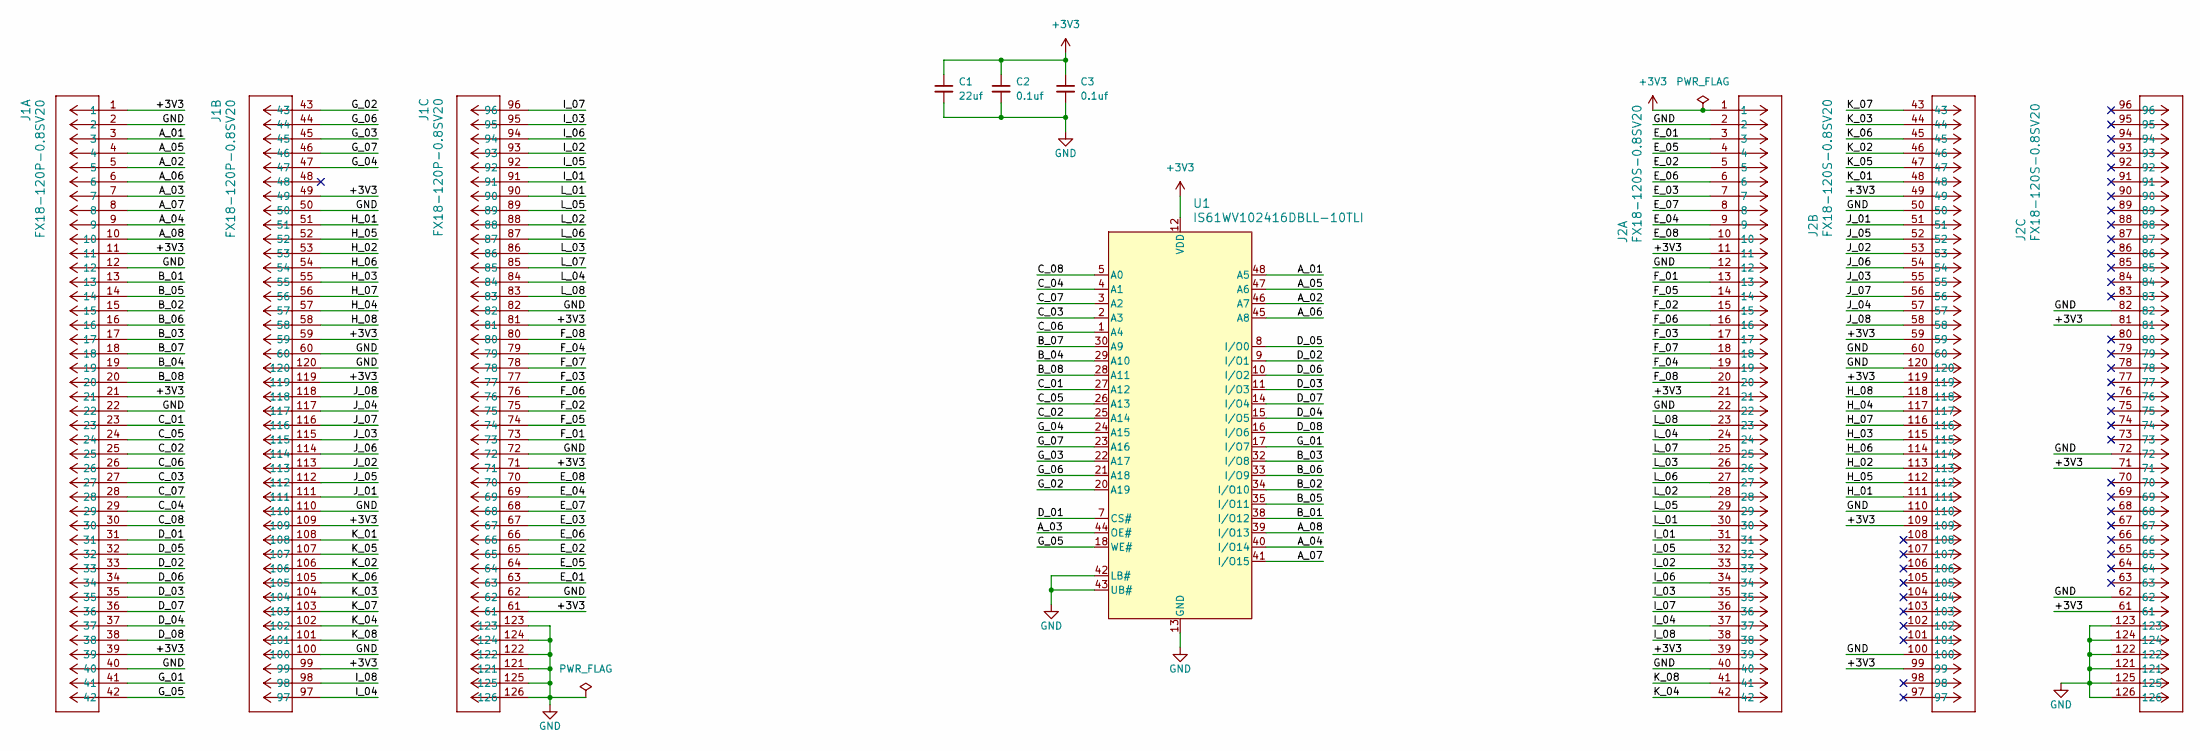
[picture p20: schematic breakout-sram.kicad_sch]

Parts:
C1: 22uf; C_0603_1608Metric; LCSC Part # C59461
C2, C3: 0.1uf; C_0402_1005Metric; LCSC Part # C1525
J1: FX18-120P-0.8SV20; CUSTOM_FX_120P-0.8SH20; Digi-Key Part Number H11865-ND
J2: FX18-120S-0.8SV20; CUSTOM_FX_120S-0.8SH20; Digi-Key Part Number H11867-ND
U1: IS61WV102416DBLL-10TLI; IS61WV102416DBLL-10TLI_ISI; LCSC Part # C1348726

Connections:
+3V3: C1.1, C2.1, C3.1, J1.1, J1.11, J1.21, J1.39, J1.49, J1.59, J1.61, J1.71, J1.81, J1.99, J1.109, J1.119, J2.1, J2.11, J2.21, J2.39, J2.49, J2.59, J2.61, J2.71, J2.81, J2.99, J2.109, J2.119, U1.12 (VDD), U1.36 (VDD)
/A_01: J1.3, U1.48 (A5)
/A_02: J1.5, U1.46 (A7)
/A_03: J1.7, U1.44 (OE#)
/A_04: J1.9, U1.40 (I/O14)
/A_05: J1.4, U1.47 (A6)
/A_06: J1.6, U1.45 (A8)
/A_07: J1.8, U1.41 (I/O15)
/A_08: J1.10, U1.39 (I/O13)
/B_01: J1.13, U1.38 (I/O12)
/B_02: J1.15, U1.34 (I/O10)
/B_03: J1.17, U1.32 (I/O8)
/B_04: J1.19, U1.29 (A10)
/B_05: J1.14, U1.35 (I/O11)
/B_06: J1.16, U1.33 (I/O9)
/B_07: J1.18, U1.30 (A9)
/B_08: J1.20, U1.28 (A11)
/C_01: J1.23, U1.27 (A12)
/C_02: J1.25, U1.25 (A14)
/C_03: J1.27, U1.2 (A3)
/C_04: J1.29, U1.4 (A1)
/C_05: J1.24, U1.26 (A13)
/C_06: J1.26, U1.1 (A4)
/C_07: J1.28, U1.3 (A2)
/C_08: J1.30, U1.5 (A0)
/D_01: J1.31, U1.7 (CS#)
/D_02: J1.33, U1.9 (I/O1)
/D_03: J1.35, U1.11 (I/O3)
/D_04: J1.37, U1.15 (I/O5)
/D_05: J1.32, U1.8 (I/O0)
/D_06: J1.34, U1.10 (I/O2)
/D_07: J1.36, U1.14 (I/O4)
/D_08: J1.38, U1.16 (I/O6)
/E_01: J1.63, J2.3
/E_02: J1.65, J2.5
/E_03: J1.67, J2.7
/E_04: J1.69, J2.9
/E_05: J1.64, J2.4
/E_06: J1.66, J2.6
/E_07: J1.68, J2.8
/E_08: J1.70, J2.10
/F_01: J1.73, J2.13
/F_02: J1.75, J2.15
/F_03: J1.77, J2.17
/F_04: J1.79, J2.19
/F_05: J1.74, J2.14
/F_06: J1.76, J2.16
/F_07: J1.78, J2.18
/F_08: J1.80, J2.20
/G_01: J1.41, U1.17 (I/O7)
/G_02: J1.43, U1.20 (A19)
/G_03: J1.45, U1.22 (A17)
/G_04: J1.47, U1.24 (A15)
/G_05: J1.42, U1.18 (WE#)
/G_06: J1.44, U1.21 (A18)
/G_07: J1.46, U1.23 (A16)
/H_01: J1.51, J2.111
/H_02: J1.53, J2.113
/H_03: J1.55, J2.115
/H_04: J1.57, J2.117
/H_05: J1.52, J2.112
/H_06: J1.54, J2.114
/H_07: J1.56, J2.116
/H_08: J1.58, J2.118
/I_01: J1.91, J2.31
/I_02: J1.93, J2.33
/I_03: J1.95, J2.35
/I_04: J1.97, J2.37
/I_05: J1.92, J2.32
/I_06: J1.94, J2.34
/I_07: J1.96, J2.36
/I_08: J1.98, J2.38
/J_01: J1.111, J2.51
/J_02: J1.113, J2.53
/J_03: J1.115, J2.55
/J_04: J1.117, J2.57
/J_05: J1.112, J2.52
/J_06: J1.114, J2.54
/J_07: J1.116, J2.56
/J_08: J1.118, J2.58
/K_01: J1.108, J2.48
/K_02: J1.106, J2.46
/K_03: J1.104, J2.44
/K_04: J1.102, J2.42
/K_05: J1.107, J2.47
/K_06: J1.105, J2.45
/K_07: J1.103, J2.43
/K_08: J1.101, J2.41
/L_01: J1.90, J2.30
/L_02: J1.88, J2.28
/L_03: J1.86, J2.26
/L_04: J1.84, J2.24
/L_05: J1.89, J2.29
/L_06: J1.87, J2.27
/L_07: J1.85, J2.25
/L_08: J1.83, J2.23
GND: C1.2, C2.2, C3.2, J1.2, J1.12, J1.22, J1.40, J1.50, J1.60, J1.62, J1.72, J1.82, J1.100, J1.110, J1.120, J1.121, J1.122, J1.123, J1.124, J1.125, J1.126, J2.2, J2.12, J2.22, J2.40, J2.50, J2.60, J2.62, J2.72, J2.82, J2.100, J2.110, J2.120, J2.121, J2.122, J2.123, J2.124, J2.125, J2.126, U1.13 (GND), U1.37 (GND), U1.42 (LB#), U1.43 (UB#)

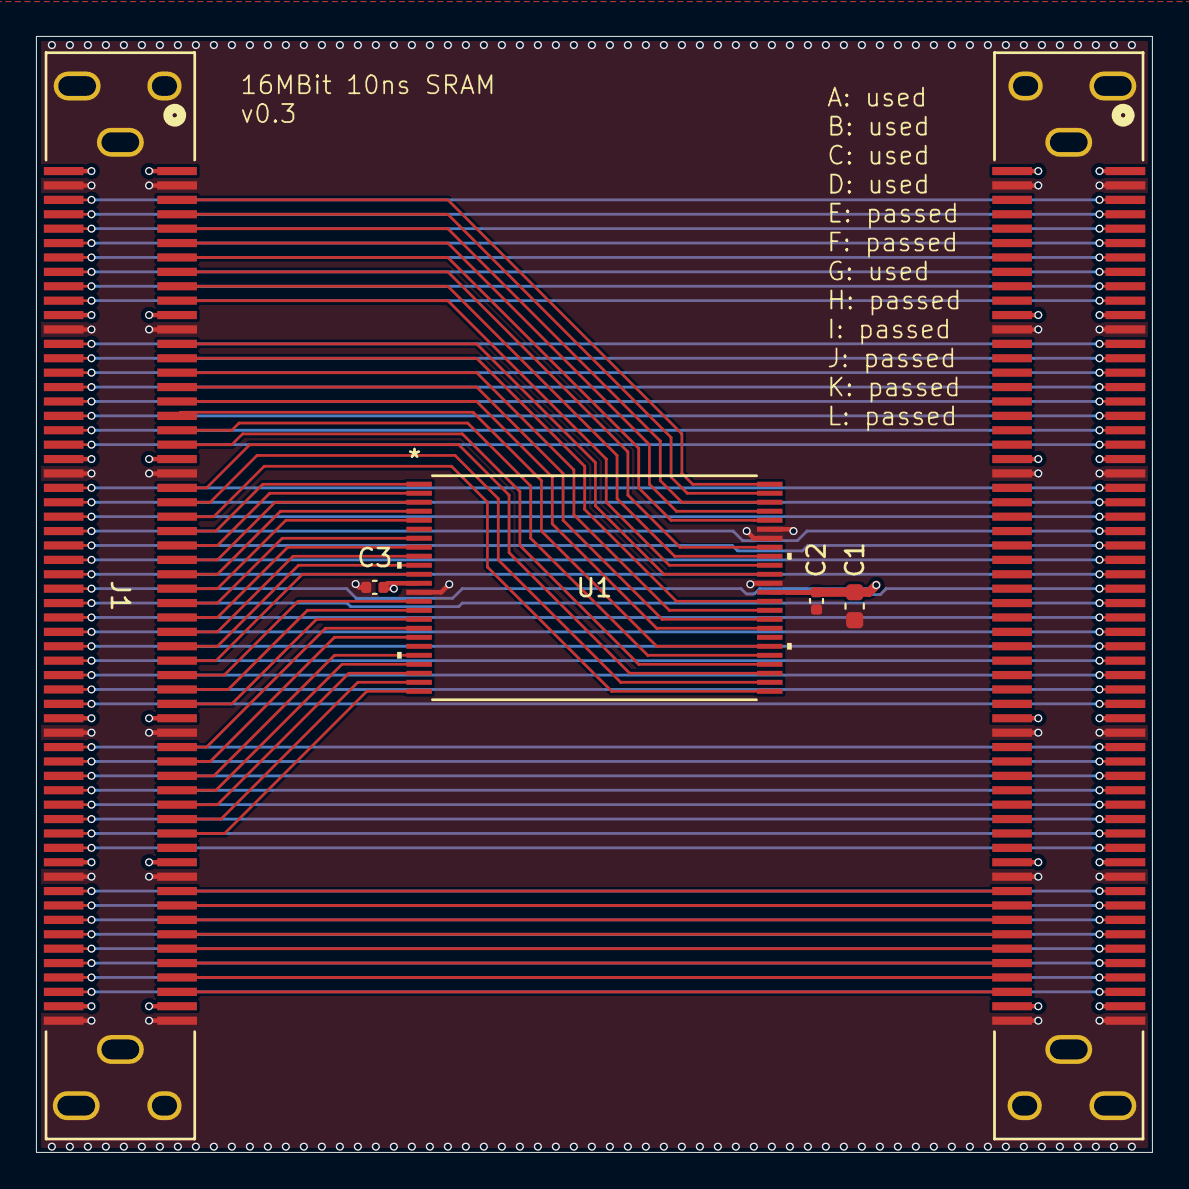
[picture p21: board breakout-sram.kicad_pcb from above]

Board: 4 copper layers, 62.0 x 62.0 mm, 6 parts (0 on the bottom side), 97 nets.

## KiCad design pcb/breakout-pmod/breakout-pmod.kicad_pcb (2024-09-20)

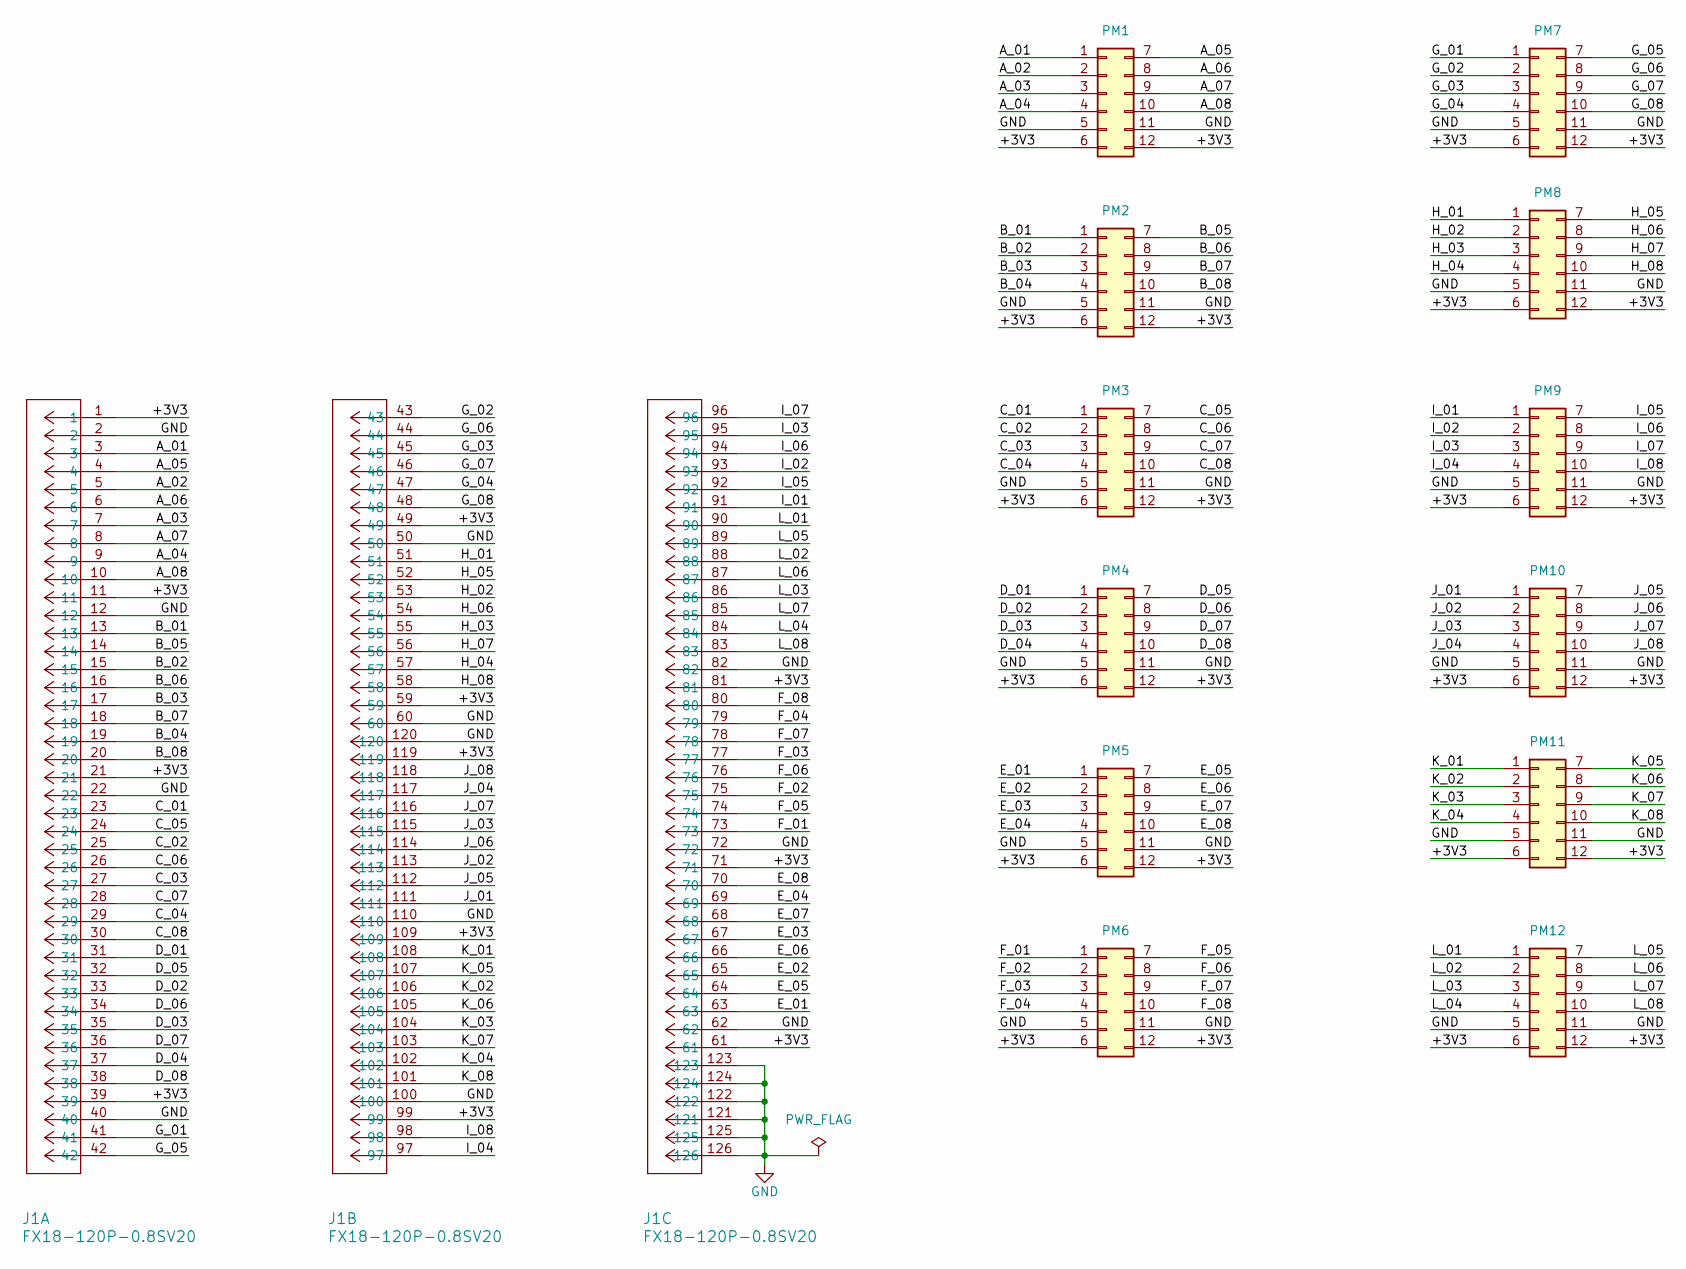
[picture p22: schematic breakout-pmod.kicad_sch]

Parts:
J1: FX18-120P-0.8SV20; CUSTOM_FX_120P-0.8SH20; Digi-Key Part Number H11865-ND
PM1, PM2, PM3, PM4, PM5, PM6, PM7, PM8, PM9, PM10: Conn_02x06_Top_Bottom; PMOD_12p_Horizontal; Digi-Key Part Number S5559-ND
PM11, PM12: Conn_02x06_Top_Bottom; PMOD_12p_Horizontal; Digi-Key Part Number S7109-ND

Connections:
/+3V3: J1.1, J1.11, J1.21, J1.39, J1.49, J1.59, J1.61, J1.71, J1.81, J1.99, J1.109, J1.119, PM1.6, PM1.12, PM2.6, PM2.12, PM3.6, PM3.12, PM4.6, PM4.12, PM5.6, PM5.12, PM6.6, PM6.12, PM7.6, PM7.12, PM8.6, PM8.12, PM9.6, PM9.12, PM10.6, PM10.12, PM11.6, PM11.12, PM12.6, PM12.12
/A_01: J1.3, PM1.1
/A_02: J1.5, PM1.2
/A_03: J1.7, PM1.3
/A_04: J1.9, PM1.4
/A_05: J1.4, PM1.7
/A_06: J1.6, PM1.8
/A_07: J1.8, PM1.9
/A_08: J1.10, PM1.10
/B_01: J1.13, PM2.1
/B_02: J1.15, PM2.2
/B_03: J1.17, PM2.3
/B_04: J1.19, PM2.4
/B_05: J1.14, PM2.7
/B_06: J1.16, PM2.8
/B_07: J1.18, PM2.9
/B_08: J1.20, PM2.10
/C_01: J1.23, PM3.1
/C_02: J1.25, PM3.2
/C_03: J1.27, PM3.3
/C_04: J1.29, PM3.4
/C_05: J1.24, PM3.7
/C_06: J1.26, PM3.8
/C_07: J1.28, PM3.9
/C_08: J1.30, PM3.10
/D_01: J1.31, PM4.1
/D_02: J1.33, PM4.2
/D_03: J1.35, PM4.3
/D_04: J1.37, PM4.4
/D_05: J1.32, PM4.7
/D_06: J1.34, PM4.8
/D_07: J1.36, PM4.9
/D_08: J1.38, PM4.10
/E_01: J1.63, PM5.1
/E_02: J1.65, PM5.2
/E_03: J1.67, PM5.3
/E_04: J1.69, PM5.4
/E_05: J1.64, PM5.7
/E_06: J1.66, PM5.8
/E_07: J1.68, PM5.9
/E_08: J1.70, PM5.10
/F_01: J1.73, PM6.1
/F_02: J1.75, PM6.2
/F_03: J1.77, PM6.3
/F_04: J1.79, PM6.4
/F_05: J1.74, PM6.7
/F_06: J1.76, PM6.8
/F_07: J1.78, PM6.9
/F_08: J1.80, PM6.10
/G_01: J1.41, PM7.1
/G_02: J1.43, PM7.2
/G_03: J1.45, PM7.3
/G_04: J1.47, PM7.4
/G_05: J1.42, PM7.7
/G_06: J1.44, PM7.8
/G_07: J1.46, PM7.9
/G_08: J1.48, PM7.10
/H_01: J1.51, PM8.1
/H_02: J1.53, PM8.2
/H_03: J1.55, PM8.3
/H_04: J1.57, PM8.4
/H_05: J1.52, PM8.7
/H_06: J1.54, PM8.8
/H_07: J1.56, PM8.9
/H_08: J1.58, PM8.10
/I_01: J1.91, PM9.1
/I_02: J1.93, PM9.2
/I_03: J1.95, PM9.3
/I_04: J1.97, PM9.4
/I_05: J1.92, PM9.7
/I_06: J1.94, PM9.8
/I_07: J1.96, PM9.9
/I_08: J1.98, PM9.10
/J_01: J1.111, PM10.1
/J_02: J1.113, PM10.2
/J_03: J1.115, PM10.3
/J_04: J1.117, PM10.4
/J_05: J1.112, PM10.7
/J_06: J1.114, PM10.8
/J_07: J1.116, PM10.9
/J_08: J1.118, PM10.10
/K_01: J1.108, PM11.1
/K_02: J1.106, PM11.2
/K_03: J1.104, PM11.3
/K_04: J1.102, PM11.4
/K_05: J1.107, PM11.7
/K_06: J1.105, PM11.8
/K_07: J1.103, PM11.9
/K_08: J1.101, PM11.10
/L_01: J1.90, PM12.1
/L_02: J1.88, PM12.2
/L_03: J1.86, PM12.3
/L_04: J1.84, PM12.4
/L_05: J1.89, PM12.7
/L_06: J1.87, PM12.8
/L_07: J1.85, PM12.9
/L_08: J1.83, PM12.10
GND: J1.2, J1.12, J1.22, J1.40, J1.50, J1.60, J1.62, J1.72, J1.82, J1.100, J1.110, J1.120, J1.121, J1.122, J1.123, J1.124, J1.125, J1.126, PM1.5, PM1.11, PM2.5, PM2.11, PM3.5, PM3.11, PM4.5, PM4.11, PM5.5, PM5.11, PM6.5, PM6.11, PM7.5, PM7.11, PM8.5, PM8.11, PM9.5, PM9.11, PM10.5, PM10.11, PM11.5, PM11.11, PM12.5, PM12.11

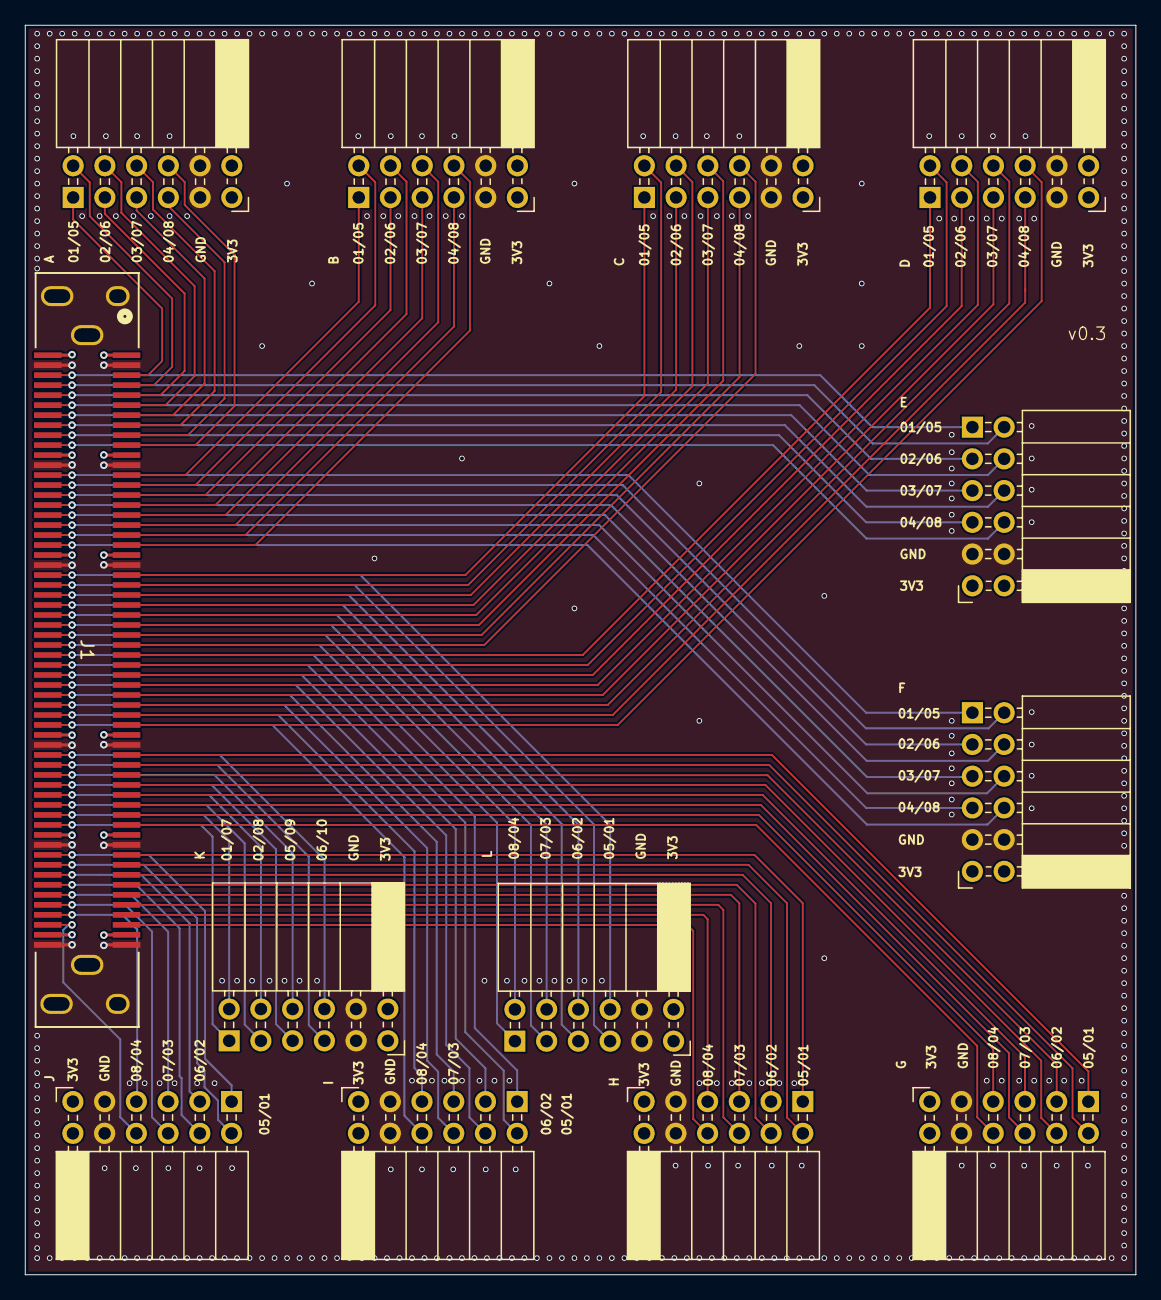
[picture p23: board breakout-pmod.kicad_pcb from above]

Board: 4 copper layers, 88.9 x 100.0 mm, 13 parts (0 on the bottom side), 98 nets.

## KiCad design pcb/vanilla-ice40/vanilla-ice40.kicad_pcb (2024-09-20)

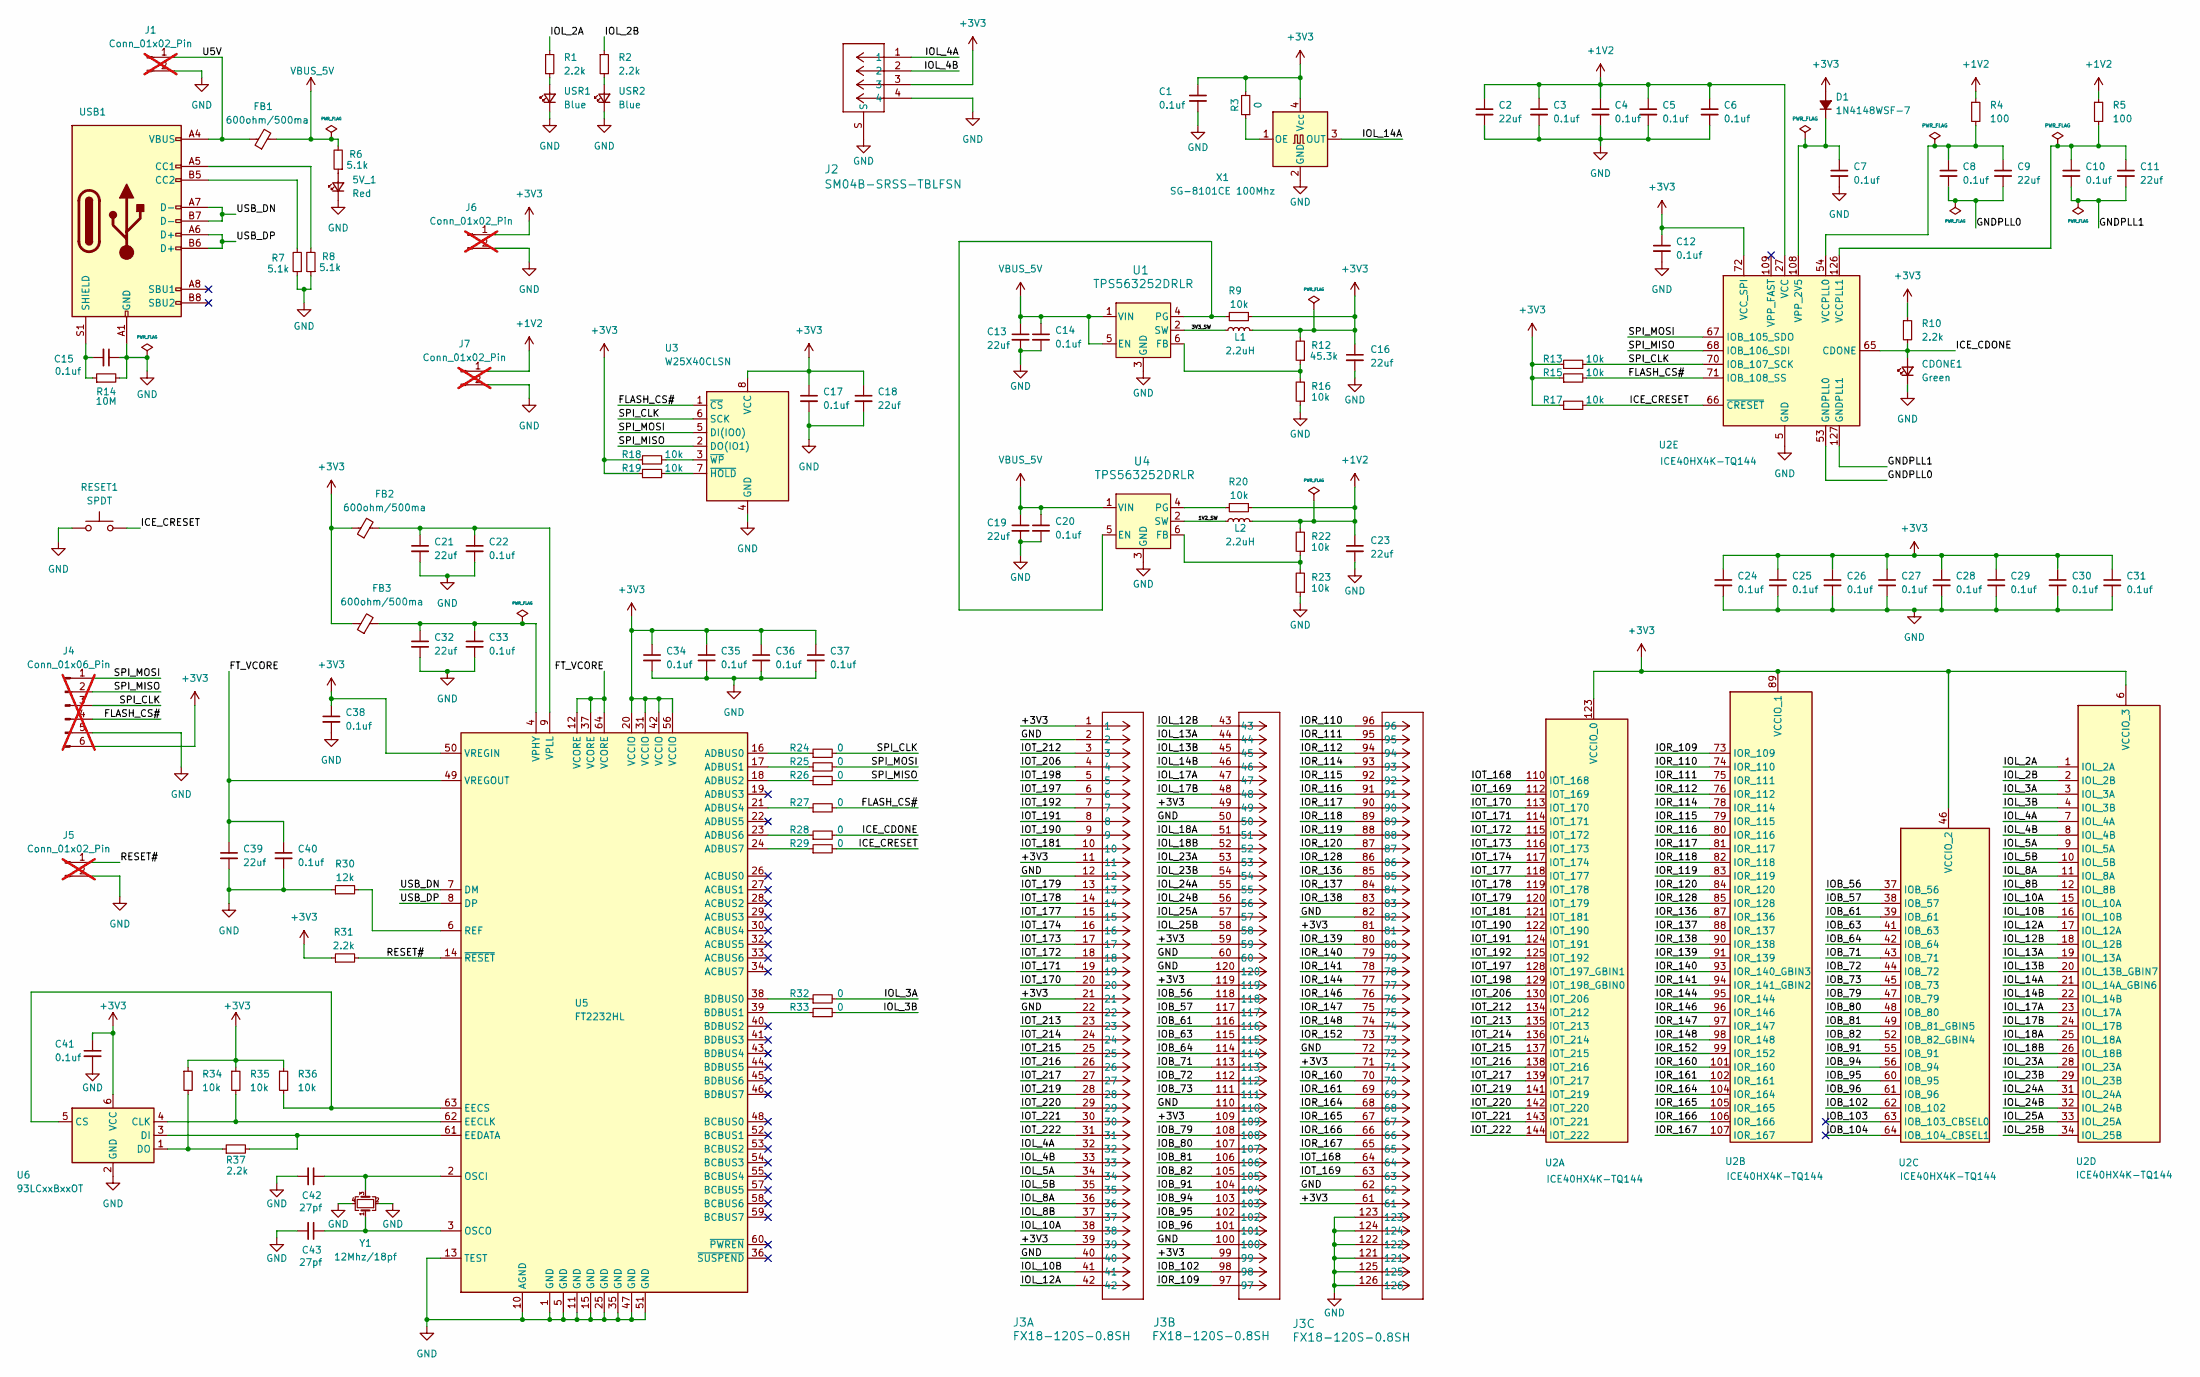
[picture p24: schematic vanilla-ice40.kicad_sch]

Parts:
5V_1: Red; D_0603_1608Metric; LCSC Part # C2286
C1, C3, C4, C5, C6, C7, C8, C10, C12, C14, C15, C17, C20, C22, C24, C25, C26, C27, C28, C29, C30, C31, C33, C34, C35, C36, C37, C38, C40, C41: 0.1uf; C_0402_1005Metric; LCSC Part # C1525
C2, C9, C11, C13, C16, C18, C19, C21, C23, C32, C39: 22uf; C_0603_1608Metric; LCSC Part # C59461
C42, C43: 27pf; C_0402_1005Metric; LCSC Part # C1555
CDONE1: Green; D_0603_1608Metric; LCSC Part # C434423
D1: 1N4148WSF-7; D_SOD-323F; LCSC Part # C119617
FB1, FB2, FB3: 600ohm/500ma; L_0603_1608Metric; LCSC Part # C1002
J1, J5, J6, J7: Conn_01x02_Pin; PinHeader_1x02_P2.54mm_Vertical; not fitted
J2: SM04B-SRSS-TBLFSN; CONN_SM04B_JST; LCSC Part # C160404
J3: FX18-120S-0.8SH; CUSTOM_FX_120S-0.8SH20; LCSC Part # C598059
J4: Conn_01x06_Pin; PinHeader_1x06_P2.54mm_Vertical; not fitted
L1, L2: 2.2uH; L_1008_2520Metric; LCSC Part # C391305
R1, R2, R10, R31, R37: 2.2k; R_0603_1608Metric; LCSC Part # C4190
R3, R24, R25, R26, R27, R28, R29, R32, R33: 0; R_0603_1608Metric; LCSC Part # C21189
R4, R5: 100; R_0603_1608Metric; LCSC Part # C22775
R6, R7, R8: 5.1k; R_0603_1608Metric; LCSC Part # C23186
R9, R13, R15, R16, R17, R18, R19, R20, R22, R23, R34, R35, R36: 10k; R_0603_1608Metric; LCSC Part # C25804
R12: 45.3k; R_0603_1608Metric; LCSC Part # C23058
R14: 10M; R_0603_1608Metric; LCSC Part # C7250
R30: 12k; R_0603_1608Metric; LCSC Part # C22790
RESET1: SPDT; SW_SPST_PTS810; LCSC Part # C221897
U1, U4: TPS563252DRLR; SOT6_DRL_TEX; LCSC Part # C19188399
U2: ICE40HX4K-TQ144; TQFP-144_20x20mm_P0.5mm; LCSC Part # C1521989
U3: W25X40CLSN; SOIC-8_3.9x4.9mm_P1.27mm; LCSC Part # C19617
U5: FT2232HL; LQFP-64_10x10mm_P0.5mm; LCSC Part # C27882
U6: 93LCxxBxxOT; SOT-23-6; LCSC Part # C190271
USB1: USB_C_Receptacle_USB2.0_16P; USB_C_Receptacle_GCT_USB4105-xx-A_16P_TopMnt_Horizontal; LCSC Part # C2686968
USR1, USR2: Blue; D_0603_1608Metric; LCSC Part # C965807
X1: SG-8101CE 100Mhz; Oscillator_SMD_SeikoEpson_SG8002CE-4Pin_3.2x2.5mm; LCSC Part # C390559
Y1: 12Mhz/18pf; Crystal_SMD_3225-4Pin_3.2x2.5mm; LCSC Part # C390764

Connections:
+1V2: C2.1, C3.1, C4.1, C5.1, C6.1, C23.1, J7.1, L2.2, R4.1, R5.1, R20.1, R22.2, U2.27 (VCC), U2.40 (VCC), U2.92 (VCC), U2.111 (VCC)
+3V3: C1.1, C12.1, C16.1, C17.1, C18.1, C24.1, C25.1, C26.1, C27.1, C28.1, C29.1, C30.1, C31.1, C34.1, C35.1, C36.1, C37.1, C38.1, C41.1, D1.2 (A), FB2.1, FB3.1, J2.3, J3.1, J3.11, J3.21, J3.39, J3.49, J3.59, J3.61, J3.71, J3.81, J3.99, J3.109, J3.119, J4.6, J6.1, L1.2, R3.2, R9.1, R10.1, R12.2, R13.1, R15.1, R17.1, R18.1, R19.1, R31.1, R34.1, R35.1, R36.1, U2.6 (VCCIO_3), U2.30 (VCCIO_3), U2.46 (VCCIO_2), U2.57 (VCCIO_2), U2.72 (VCC_SPI), U2.89 (VCCIO_1), U2.100 (VCCIO_1), U2.123 (VCCIO_0), U2.131 (VCCIO_0), U3.8 (VCC), U5.20 (VCCIO), U5.31 (VCCIO), U5.42 (VCCIO), U5.50 (VREGIN), U5.56 (VCCIO), U6.6 (VCC), X1.4 (Vcc)
/1V2_SW: L2.1, U4.2 (SW)
/3V3_SW: L1.1, U1.2 (SW)
/FLASH_CS#: J4.4, R15.2, R27.2, U2.71 (IOB_108_SS), U3.1 (~CS)
/FT_VCORE: C39.1, C40.1, U5.12 (VCORE), U5.37 (VCORE), U5.49 (VREGOUT), U5.64 (VCORE)
/GNDPLL0: C8.2, C9.2, U2.53 (GNDPLL0)
/GNDPLL1: C10.2, C11.2, U2.127 (GNDPLL1)
/ICE_CDONE: CDONE1.2 (A), R10.2, R28.2, U2.65 (CDONE)
/ICE_CRESET: R17.2, R29.2, RESET1.2, U2.66 (~CRESET)
/IOB_56: J3.118, U2.37 (IOB_56)
/IOB_57: J3.117, U2.38 (IOB_57)
/IOB_61: J3.116, U2.39 (IOB_61)
/IOB_63: J3.115, U2.41 (IOB_63)
/IOB_64: J3.114, U2.42 (IOB_64)
/IOB_71: J3.113, U2.43 (IOB_71)
/IOB_72: J3.112, U2.44 (IOB_72)
/IOB_73: J3.111, U2.45 (IOB_73)
/IOB_79: J3.108, U2.47 (IOB_79)
/IOB_80: J3.107, U2.48 (IOB_80)
/IOB_81: J3.106, U2.49 (IOB_81_GBIN5)
/IOB_82: J3.105, U2.52 (IOB_82_GBIN4)
/IOB_91: J3.104, U2.55 (IOB_91)
/IOB_94: J3.103, U2.56 (IOB_94)
/IOB_95: J3.102, U2.60 (IOB_95)
/IOB_96: J3.101, U2.61 (IOB_96)
/IOB_102: J3.98, U2.62 (IOB_102)
/IOB_103: U2.63 (IOB_103_CBSEL0)
/IOB_104: U2.64 (IOB_104_CBSEL1)
/IOL_2A: R1.1, U2.1 (IOL_2A)
/IOL_2B: R2.1, U2.2 (IOL_2B)
/IOL_3A: R32.2, U2.3 (IOL_3A)
/IOL_3B: R33.2, U2.4 (IOL_3B)
/IOL_4A: J2.1, J3.32, U2.7 (IOL_4A)
/IOL_4B: J2.2, J3.33, U2.8 (IOL_4B)
/IOL_5A: J3.34, U2.9 (IOL_5A)
/IOL_5B: J3.35, U2.10 (IOL_5B)
/IOL_8A: J3.36, U2.11 (IOL_8A)
/IOL_8B: J3.37, U2.12 (IOL_8B)
/IOL_10A: J3.38, U2.15 (IOL_10A)
/IOL_10B: J3.41, U2.16 (IOL_10B)
/IOL_12A: J3.42, U2.17 (IOL_12A)
/IOL_12B: J3.43, U2.18 (IOL_12B)
/IOL_13A: J3.44, U2.19 (IOL_13A)
/IOL_13B: J3.45, U2.20 (IOL_13B_GBIN7)
/IOL_14A: U2.21 (IOL_14A_GBIN6), X1.3 (OUT)
/IOL_14B: J3.46, U2.22 (IOL_14B)
/IOL_17A: J3.47, U2.23 (IOL_17A)
/IOL_17B: J3.48, U2.24 (IOL_17B)
/IOL_18A: J3.51, U2.25 (IOL_18A)
/IOL_18B: J3.52, U2.26 (IOL_18B)
/IOL_23A: J3.53, U2.28 (IOL_23A)
/IOL_23B: J3.54, U2.29 (IOL_23B)
/IOL_24A: J3.55, U2.31 (IOL_24A)
/IOL_24B: J3.56, U2.32 (IOL_24B)
/IOL_25A: J3.57, U2.33 (IOL_25A)
/IOL_25B: J3.58, U2.34 (IOL_25B)
/IOR_109: J3.97, U2.73 (IOR_109)
/IOR_110: J3.96, U2.74 (IOR_110)
/IOR_111: J3.95, U2.75 (IOR_111)
/IOR_112: J3.94, U2.76 (IOR_112)
/IOR_114: J3.93, U2.78 (IOR_114)
/IOR_115: J3.92, U2.79 (IOR_115)
/IOR_116: J3.91, U2.80 (IOR_116)
/IOR_117: J3.90, U2.81 (IOR_117)
/IOR_118: J3.89, U2.82 (IOR_118)
/IOR_119: J3.88, U2.83 (IOR_119)
/IOR_120: J3.87, U2.84 (IOR_120)
/IOR_128: J3.86, U2.85 (IOR_128)
/IOR_136: J3.85, U2.87 (IOR_136)
/IOR_137: J3.84, U2.88 (IOR_137)
/IOR_138: J3.83, U2.90 (IOR_138)
/IOR_139: J3.80, U2.91 (IOR_139)
/IOR_140: J3.79, U2.93 (IOR_140_GBIN3)
/IOR_141: J3.78, U2.94 (IOR_141_GBIN2)
/IOR_144: J3.77, U2.95 (IOR_144)
/IOR_146: J3.76, U2.96 (IOR_146)
/IOR_147: J3.75, U2.97 (IOR_147)
/IOR_148: J3.74, U2.98 (IOR_148)
/IOR_152: J3.73, U2.99 (IOR_152)
/IOR_160: J3.70, U2.101 (IOR_160)
/IOR_161: J3.69, U2.102 (IOR_161)
/IOR_164: J3.68, U2.104 (IOR_164)
/IOR_165: J3.67, U2.105 (IOR_165)
/IOR_166: J3.66, U2.106 (IOR_166)
/IOR_167: J3.65, U2.107 (IOR_167)
/IOT_168: J3.64, U2.110 (IOT_168)
/IOT_169: J3.63, U2.112 (IOT_169)
/IOT_170: J3.20, U2.113 (IOT_170)
/IOT_171: J3.19, U2.114 (IOT_171)
/IOT_172: J3.18, U2.115 (IOT_172)
/IOT_173: J3.17, U2.116 (IOT_173)
/IOT_174: J3.16, U2.117 (IOT_174)
/IOT_177: J3.15, U2.118 (IOT_177)
/IOT_178: J3.14, U2.119 (IOT_178)
/IOT_179: J3.13, U2.120 (IOT_179)
/IOT_181: J3.10, U2.121 (IOT_181)
/IOT_190: J3.9, U2.122 (IOT_190)
/IOT_191: J3.8, U2.124 (IOT_191)
/IOT_192: J3.7, U2.125 (IOT_192)
/IOT_197: J3.6, U2.128 (IOT_197_GBIN1)
/IOT_198: J3.5, U2.129 (IOT_198_GBIN0)
/IOT_206: J3.4, U2.130 (IOT_206)
/IOT_212: J3.3, U2.134 (IOT_212)
/IOT_213: J3.23, U2.135 (IOT_213)
/IOT_214: J3.24, U2.136 (IOT_214)
/IOT_215: J3.25, U2.137 (IOT_215)
/IOT_216: J3.26, U2.138 (IOT_216)
/IOT_217: J3.27, U2.139 (IOT_217)
/IOT_219: J3.28, U2.141 (IOT_219)
/IOT_220: J3.29, U2.142 (IOT_220)
/IOT_221: J3.30, U2.143 (IOT_221)
/IOT_222: J3.31, U2.144 (IOT_222)
/RESET#: J5.1, R31.2, U5.14 (~RESET)
/SPI_CLK: J4.3, R13.2, R24.2, U2.70 (IOB_107_SCK), U3.6 (SCK)
/SPI_MISO: J4.2, R26.2, U2.68 (IOB_106_SDI), U3.2 (DO(IO1))
/SPI_MOSI: J4.1, R25.2, U2.67 (IOB_105_SDO), U3.5 (DI(IO0))
/U5V: FB1.1, J1.1, USB1.A4 (VBUS), USB1.A9 (VBUS), USB1.B4 (VBUS), USB1.B9 (VBUS)
/USB_DN: U5.7 (DM), USB1.A7 (D-), USB1.B7 (D-)
/USB_DP: U5.8 (DP), USB1.A6 (D+), USB1.B6 (D+)
GND: 5V_1.1 (K), C1.2, C2.2, C3.2, C4.2, C5.2, C6.2, C7.2, C12.2, C13.2, C14.2, C15.1, C16.2, C17.2, C18.2, C19.2, C20.2, C21.2, C22.2, C23.2, C24.2, C25.2, C26.2, C27.2, C28.2, C29.2, C30.2, C31.2, C32.2, C33.2, C34.2, C35.2, C36.2, C37.2, C38.2, C39.2, C40.2, C41.2, C42.2, C43.2, CDONE1.1 (K), J1.2, J2.4, J2.S, J3.2, J3.12, J3.22, J3.40, J3.50, J3.60, J3.62, J3.72, J3.82, J3.100, J3.110, J3.120, J3.121, J3.122, J3.123, J3.124, J3.125, J3.126, J4.5, J5.2, J6.2, J7.2, R7.1, R8.1, R14.2, R16.1, R23.1, R30.1, RESET1.1, U1.3 (GND), U2.5 (GND), U2.13 (GND), U2.14 (GND), U2.59 (GND), U2.69 (GND), U2.86 (GND), U2.103 (GND), U2.132 (GND), U2.140 (GND), U3.4 (GND), U4.3 (GND), U5.1 (GND), U5.5 (GND), U5.10 (AGND), U5.11 (GND), U5.13 (TEST), U5.15 (GND), U5.25 (GND), U5.35 (GND), U5.47 (GND), U5.51 (GND), U6.2 (GND), USB1.A1 (GND), USB1.A12 (GND), USB1.B1 (GND), USB1.B12 (GND), USR1.1 (K), USR2.1 (K), X1.2 (GND), Y1.2, Y1.4
unnamed: 5V_1.2 (A), R6.1
unnamed: C7.1, D1.1 (K), U2.108 (VPP_2V5)
unnamed: R12.1, R16.2, U1.6 (FB)
unnamed: R9.2, U1.4 (PG), U4.5 (EN)
unnamed: C8.1, C9.1, R4.2, U2.54 (VCCPLL0)
unnamed: C10.1, C11.1, R5.2, U2.126 (VCCPLL1)
unnamed: R19.2, U3.7 (~HOLD)
unnamed: R18.2, U3.3 (~WP)
unnamed: R22.1, R23.2, U4.6 (FB)
unnamed: R20.2, U4.4 (PG)
unnamed: R24.1, U5.16 (ADBUS0)
unnamed: R25.1, U5.17 (ADBUS1)
unnamed: R26.1, U5.18 (ADBUS2)
unnamed: R27.1, U5.21 (ADBUS4)
unnamed: R28.1, U5.23 (ADBUS6)
unnamed: R29.1, U5.24 (ADBUS7)
unnamed: R32.1, U5.38 (BDBUS0)
unnamed: R33.1, U5.39 (BDBUS1)
unnamed: R35.2, U5.62 (EECLK), U6.4 (CLK)
unnamed: R36.2, U5.63 (EECS), U6.5 (CS)
unnamed: R37.2, U5.61 (EEDATA), U6.3 (DI)
unnamed: C42.1, U5.2 (OSCI), Y1.3
unnamed: C43.1, U5.3 (OSCO), Y1.1
unnamed: R30.2, U5.6 (REF)
unnamed: C32.1, C33.1, FB3.2, U5.4 (VPHY)
unnamed: C21.1, C22.1, FB2.2, U5.9 (VPLL)
unnamed: R34.2, R37.1, U6.1 (DO)
unnamed: R8.2, USB1.A5 (CC1)
unnamed: R7.2, USB1.B5 (CC2)
unnamed: C15.2, R14.1, USB1.S1 (SHIELD)
unnamed: R1.2, USR1.2 (A)
unnamed: R2.2, USR2.2 (A)
unnamed: R3.1, X1.1 (OE)
VBUS_5V: C13.1, C14.1, C19.1, C20.1, FB1.2, R6.2, U1.1 (VIN), U1.5 (EN), U4.1 (VIN)

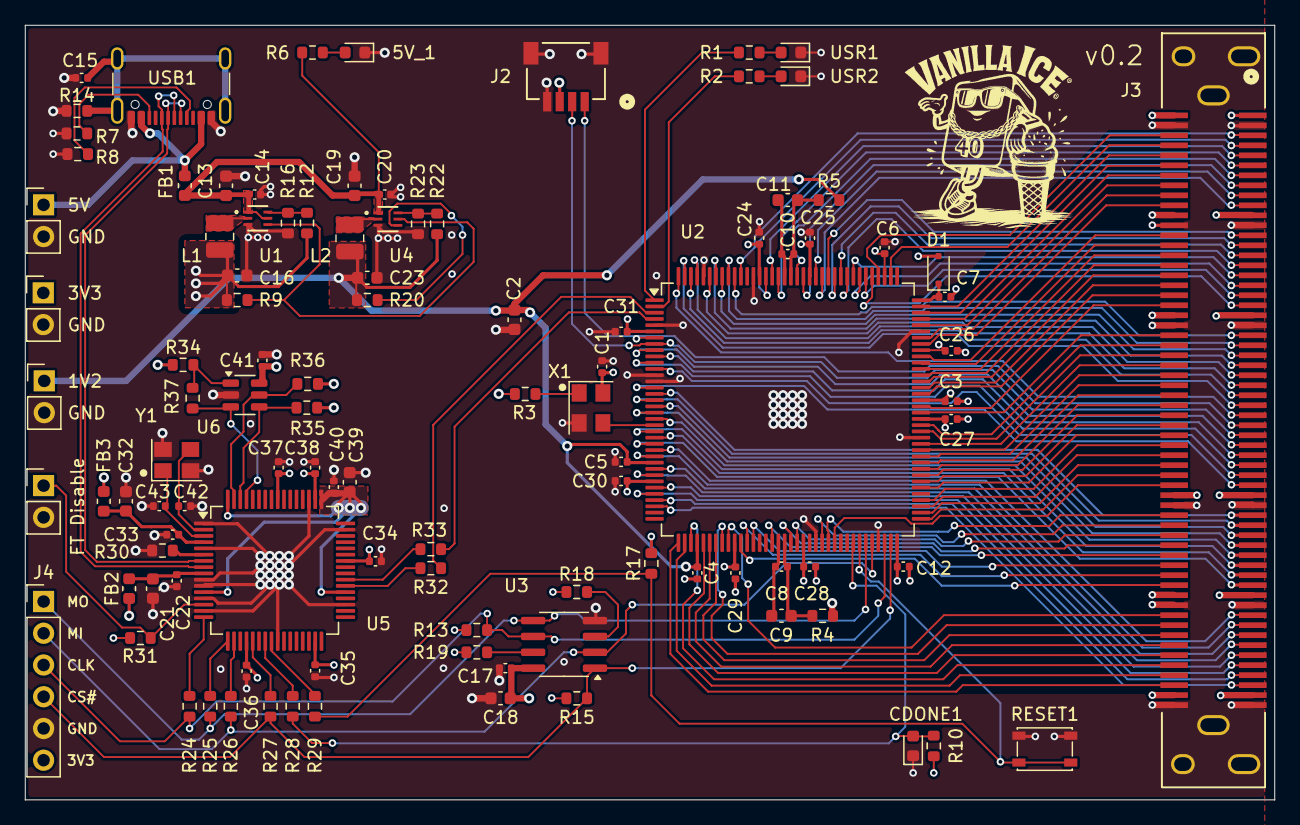
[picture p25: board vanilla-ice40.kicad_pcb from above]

Board: 4 copper layers, 100.0 x 62.0 mm, 105 parts (0 on the bottom side), 153 nets.

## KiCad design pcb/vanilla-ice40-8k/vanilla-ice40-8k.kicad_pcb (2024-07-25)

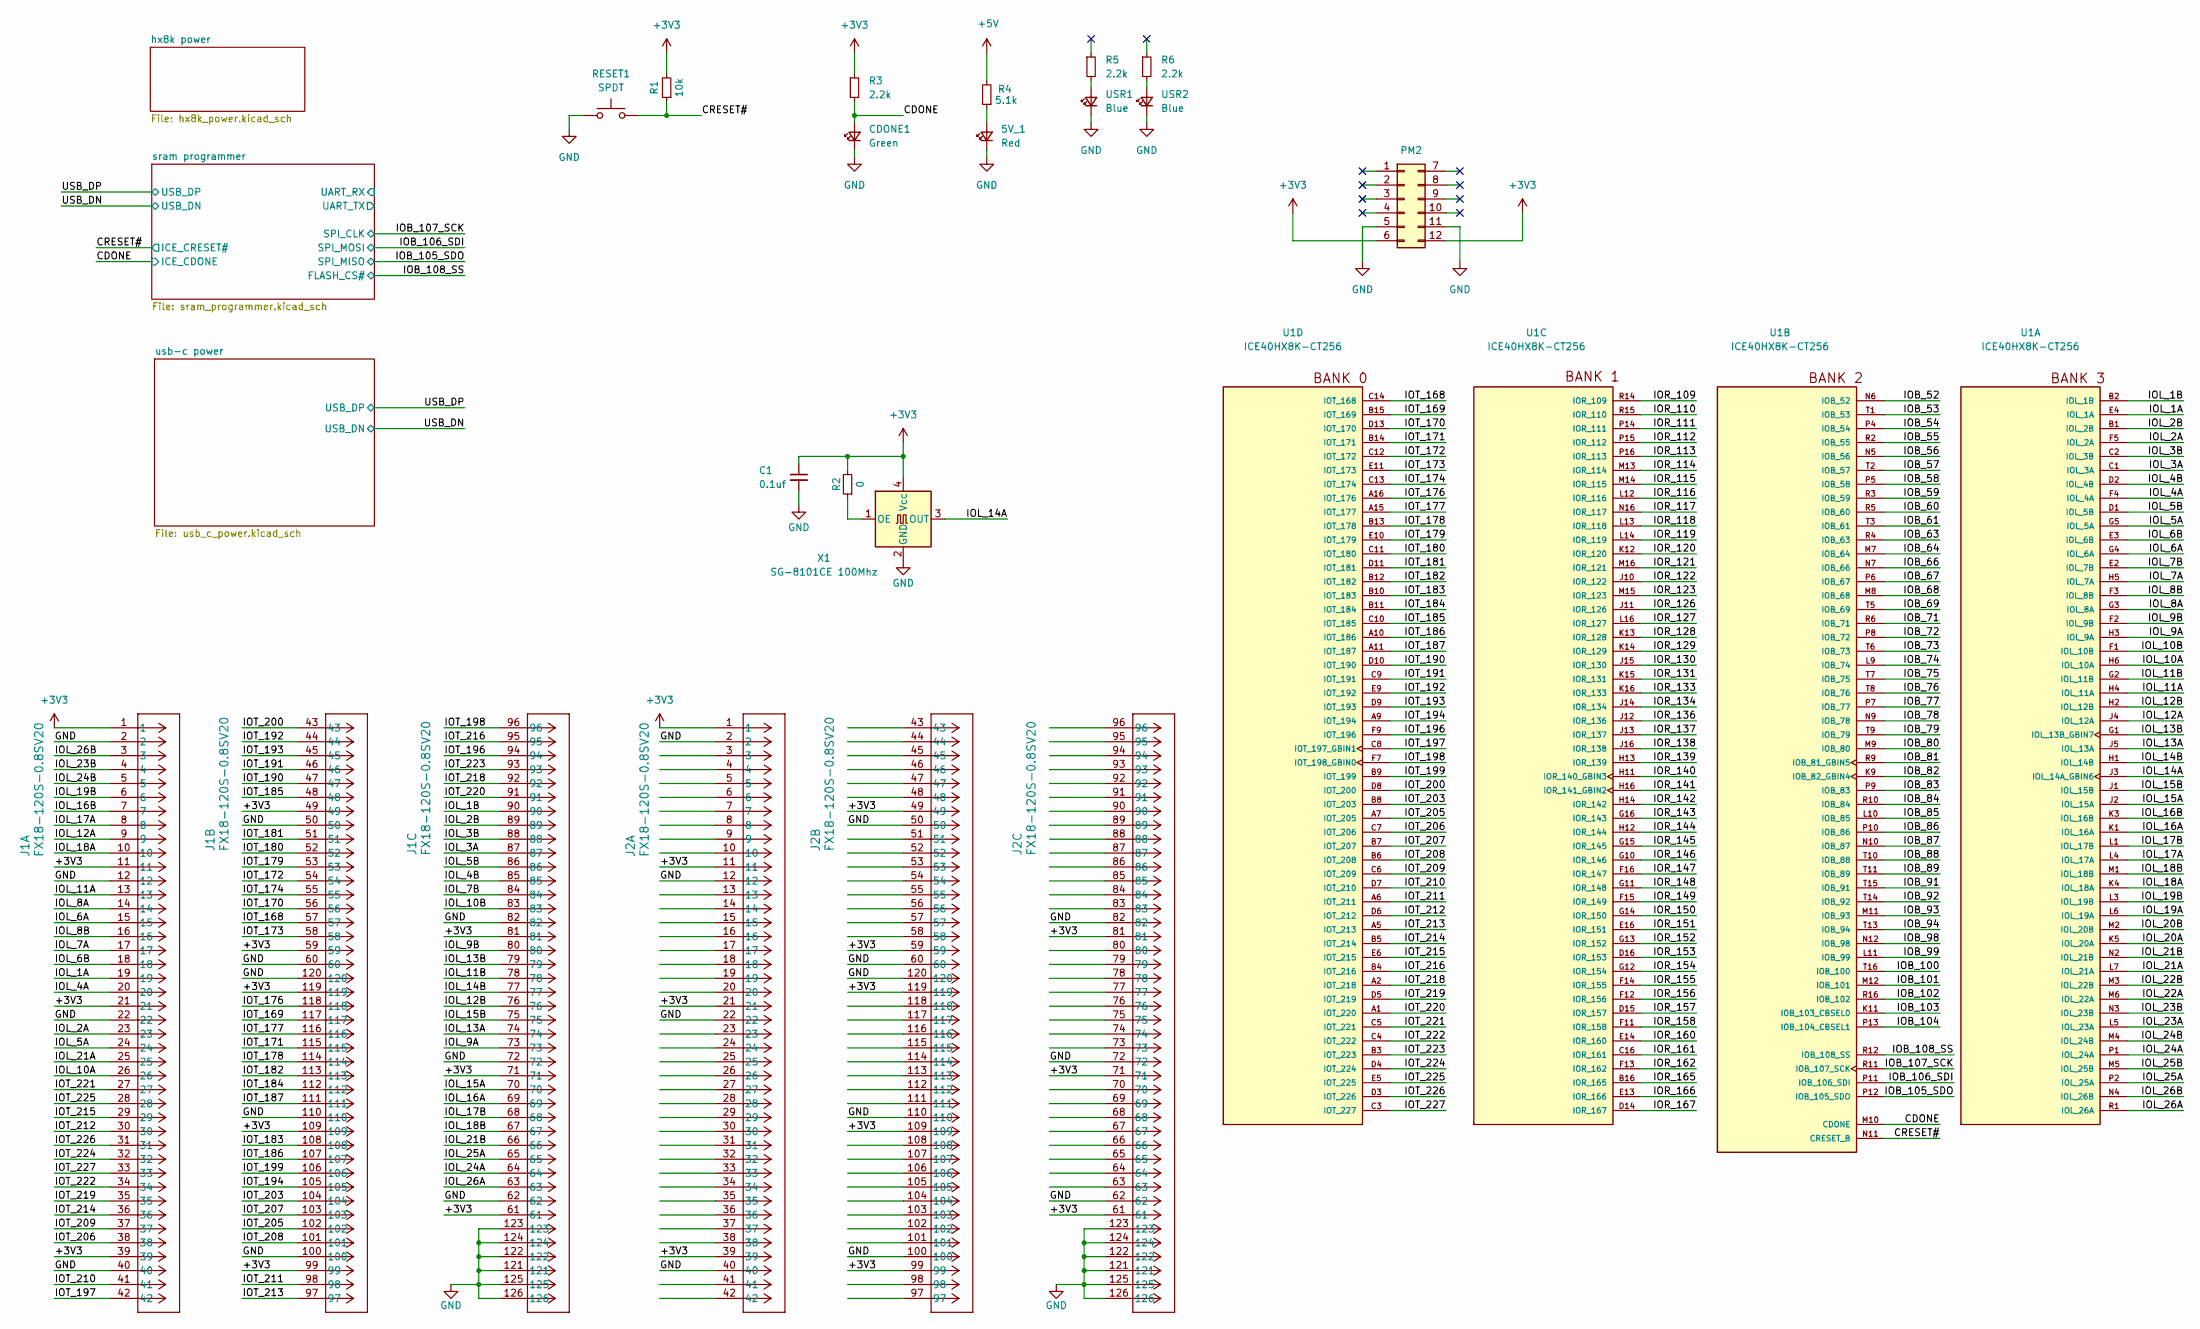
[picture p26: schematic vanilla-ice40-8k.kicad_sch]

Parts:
5V_1: Red; D_0603_1608Metric; LCSC Part # C2286
C1: 0.1uf; C_0402_1005Metric; LCSC Part # C1525
CDONE1: Green; D_0603_1608Metric; LCSC Part # C434423
J1, J2: FX18-120S-0.8SV20; CUSTOM_FX_120S-0.8SH20; Digi-Key Part Number H11867-ND
PM2: Conn_02x06_Top_Bottom; PMOD_12p_Horizontal; Digi-Key Part Number S5559-ND
R1: 10k; R_0603_1608Metric; LCSC Part # C25804
R2: 0; R_0603_1608Metric; LCSC Part # C21189
R3, R5, R6: 2.2k; R_0603_1608Metric; LCSC Part # C4190
R4: 5.1k; R_0603_1608Metric; LCSC Part # C23186
RESET1: SPDT; SW_SPST_PTS810; LCSC Part # C221897
U1: ICE40HX8K-CT256; BGA256C80P16X16_1400X1400X170; PART_REV 3.4
USR1, USR2: Blue; D_0603_1608Metric; LCSC Part # C965807
X1: SG-8101CE 100Mhz; Oscillator_SMD_SeikoEpson_SG8002CE-4Pin_3.2x2.5mm; LCSC Part # C390559

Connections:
+3V3: C1.1, J1.1, J1.11, J1.21, J1.39, J1.49, J1.59, J1.61, J1.71, J1.81, J1.99, J1.109, J1.119, J2.1, J2.11, J2.21, J2.39, J2.49, J2.59, J2.61, J2.71, J2.81, J2.99, J2.109, J2.119, PM2.6, PM2.12, R1.2, R2.2, R3.1, X1.4 (Vcc); also elsewhere on the board
+5V: R4.2; also elsewhere on the board
/CDONE: CDONE1.2 (A), R3.2, U1.M10 (CDONE); also elsewhere on the board
/CRESET#: R1.1, RESET1.2, U1.N11 (CRESET_B); also elsewhere on the board
/IOB_52: U1.N6 (IOB_52)
/IOB_53: U1.T1 (IOB_53)
/IOB_54: U1.P4 (IOB_54)
/IOB_55: U1.R2 (IOB_55)
/IOB_56: U1.N5 (IOB_56)
/IOB_57: U1.T2 (IOB_57)
/IOB_58: U1.P5 (IOB_58)
/IOB_59: U1.R3 (IOB_59)
/IOB_60: U1.R5 (IOB_60)
/IOB_61: U1.T3 (IOB_61)
/IOB_63: U1.R4 (IOB_63)
/IOB_64: U1.M7 (IOB_64)
/IOB_66: U1.N7 (IOB_66)
/IOB_67: U1.P6 (IOB_67)
/IOB_68: U1.M8 (IOB_68)
/IOB_69: U1.T5 (IOB_69)
/IOB_71: U1.R6 (IOB_71)
/IOB_72: U1.P8 (IOB_72)
/IOB_73: U1.T6 (IOB_73)
/IOB_74: U1.L9 (IOB_74)
/IOB_75: U1.T7 (IOB_75)
/IOB_76: U1.T8 (IOB_76)
/IOB_77: U1.P7 (IOB_77)
/IOB_78: U1.N9 (IOB_78)
/IOB_79: U1.T9 (IOB_79)
/IOB_80: U1.M9 (IOB_80)
/IOB_81: U1.R9 (IOB_81_GBIN5)
/IOB_82: U1.K9 (IOB_82_GBIN4)
/IOB_83: U1.P9 (IOB_83)
/IOB_84: U1.R10 (IOB_84)
/IOB_85: U1.L10 (IOB_85)
/IOB_86: U1.P10 (IOB_86)
/IOB_87: U1.N10 (IOB_87)
/IOB_88: U1.T10 (IOB_88)
/IOB_89: U1.T11 (IOB_89)
/IOB_91: U1.T15 (IOB_91)
/IOB_92: U1.T14 (IOB_92)
/IOB_93: U1.M11 (IOB_93)
/IOB_94: U1.T13 (IOB_94)
/IOB_98: U1.N12 (IOB_98)
/IOB_99: U1.L11 (IOB_99)
/IOB_100: U1.T16 (IOB_100)
/IOB_101: U1.M12 (IOB_101)
/IOB_102: U1.R16 (IOB_102)
/IOB_103: U1.K11 (IOB_103_CBSEL0)
/IOB_104: U1.P13 (IOB_104_CBSEL1)
/IOB_105_SDO: U1.P12 (IOB_105_SDO); also elsewhere on the board
/IOB_106_SDI: U1.P11 (IOB_106_SDI); also elsewhere on the board
/IOB_107_SCK: U1.R11 (IOB_107_SCK); also elsewhere on the board
/IOB_108_SS: U1.R12 (IOB_108_SS); also elsewhere on the board
/IOL_1A: J1.19, U1.E4 (IOL_1A)
/IOL_1B: J1.90, U1.B2 (IOL_1B)
/IOL_2A: J1.23, U1.F5 (IOL_2A)
/IOL_2B: J1.89, U1.B1 (IOL_2B)
/IOL_3A: J1.87, U1.C1 (IOL_3A)
/IOL_3B: J1.88, U1.C2 (IOL_3B)
/IOL_4A: J1.20, U1.F4 (IOL_4A)
/IOL_4B: J1.85, U1.D2 (IOL_4B)
/IOL_5A: J1.24, U1.G5 (IOL_5A)
/IOL_5B: J1.86, U1.D1 (IOL_5B)
/IOL_6A: J1.15, U1.G4 (IOL_6A)
/IOL_6B: J1.18, U1.E3 (IOL_6B)
/IOL_7A: J1.17, U1.H5 (IOL_7A)
/IOL_7B: J1.84, U1.E2 (IOL_7B)
/IOL_8A: J1.14, U1.G3 (IOL_8A)
/IOL_8B: J1.16, U1.F3 (IOL_8B)
/IOL_9A: J1.73, U1.H3 (IOL_9A)
/IOL_9B: J1.80, U1.F2 (IOL_9B)
/IOL_10A: J1.26, U1.H6 (IOL_10A)
/IOL_10B: J1.83, U1.F1 (IOL_10B)
/IOL_11A: J1.13, U1.H4 (IOL_11A)
/IOL_11B: J1.78, U1.G2 (IOL_11B)
/IOL_12A: J1.9, U1.J4 (IOL_12A)
/IOL_12B: J1.76, U1.H2 (IOL_12B)
/IOL_13A: J1.74, U1.J5 (IOL_13A)
/IOL_13B: J1.79, U1.G1 (IOL_13B_GBIN7)
/IOL_14A: U1.J3 (IOL_14A_GBIN6), X1.3 (OUT)
/IOL_14B: J1.77, U1.H1 (IOL_14B)
/IOL_15A: J1.70, U1.J2 (IOL_15A)
/IOL_15B: J1.75, U1.J1 (IOL_15B)
/IOL_16A: J1.69, U1.K1 (IOL_16A)
/IOL_16B: J1.7, U1.K3 (IOL_16B)
/IOL_17A: J1.8, U1.L4 (IOL_17A)
/IOL_17B: J1.68, U1.L1 (IOL_17B)
/IOL_18A: J1.10, U1.K4 (IOL_18A)
/IOL_18B: J1.67, U1.M1 (IOL_18B)
/IOL_19A: U1.L6 (IOL_19A)
/IOL_19B: J1.6, U1.L3 (IOL_19B)
/IOL_20A: U1.K5 (IOL_20A)
/IOL_20B: U1.M2 (IOL_20B)
/IOL_21A: J1.25, U1.L7 (IOL_21A)
/IOL_21B: J1.66, U1.N2 (IOL_21B)
/IOL_22A: U1.M6 (IOL_22A)
/IOL_22B: U1.M3 (IOL_22B)
/IOL_23A: U1.L5 (IOL_23A)
/IOL_23B: J1.4, U1.N3 (IOL_23B)
/IOL_24A: J1.64, U1.P1 (IOL_24A)
/IOL_24B: J1.5, U1.M4 (IOL_24B)
/IOL_25A: J1.65, U1.P2 (IOL_25A)
/IOL_25B: U1.M5 (IOL_25B)
/IOL_26A: J1.63, U1.R1 (IOL_26A)
/IOL_26B: J1.3, U1.N4 (IOL_26B)
/IOR_109: U1.R14 (IOR_109)
/IOR_110: U1.R15 (IOR_110)
/IOR_111: U1.P14 (IOR_111)
/IOR_112: U1.P15 (IOR_112)
/IOR_113: U1.P16 (IOR_113)
/IOR_114: U1.M13 (IOR_114)
/IOR_115: U1.M14 (IOR_115)
/IOR_116: U1.L12 (IOR_116)
/IOR_117: U1.N16 (IOR_117)
/IOR_118: U1.L13 (IOR_118)
/IOR_119: U1.L14 (IOR_119)
/IOR_120: U1.K12 (IOR_120)
/IOR_121: U1.M16 (IOR_121)
/IOR_122: U1.J10 (IOR_122)
/IOR_123: U1.M15 (IOR_123)
/IOR_126: U1.J11 (IOR_126)
/IOR_127: U1.L16 (IOR_127)
/IOR_128: U1.K13 (IOR_128)
/IOR_129: U1.K14 (IOR_129)
/IOR_130: U1.J15 (IOR_130)
/IOR_131: U1.K15 (IOR_131)
/IOR_133: U1.K16 (IOR_133)
/IOR_134: U1.J14 (IOR_134)
/IOR_136: U1.J12 (IOR_136)
/IOR_137: U1.J13 (IOR_137)
/IOR_138: U1.J16 (IOR_138)
/IOR_139: U1.H13 (IOR_139)
/IOR_140: U1.H11 (IOR_140_GBIN3)
/IOR_141: U1.H16 (IOR_141_GBIN2)
/IOR_142: U1.H14 (IOR_142)
/IOR_143: U1.G16 (IOR_143)
/IOR_144: U1.H12 (IOR_144)
/IOR_145: U1.G15 (IOR_145)
/IOR_146: U1.G10 (IOR_146)
/IOR_147: U1.F16 (IOR_147)
/IOR_148: U1.G11 (IOR_148)
/IOR_149: U1.F15 (IOR_149)
/IOR_150: U1.G14 (IOR_150)
/IOR_151: U1.E16 (IOR_151)
/IOR_152: U1.G13 (IOR_152)
/IOR_153: U1.D16 (IOR_153)
/IOR_154: U1.G12 (IOR_154)
/IOR_155: U1.F14 (IOR_155)
/IOR_156: U1.F12 (IOR_156)
/IOR_157: U1.D15 (IOR_157)
/IOR_158: U1.F11 (IOR_158)
/IOR_160: U1.E14 (IOR_160)
/IOR_161: U1.C16 (IOR_161)
/IOR_162: U1.F13 (IOR_162)
/IOR_165: U1.B16 (IOR_165)
/IOR_166: U1.E13 (IOR_166)
/IOR_167: U1.D14 (IOR_167)
/IOT_168: J1.57, U1.C14 (IOT_168)
/IOT_169: J1.117, U1.B15 (IOT_169)
/IOT_170: J1.56, U1.D13 (IOT_170)
/IOT_171: J1.115, U1.B14 (IOT_171)
/IOT_172: J1.54, U1.C12 (IOT_172)
/IOT_173: J1.58, U1.E11 (IOT_173)
/IOT_174: J1.55, U1.C13 (IOT_174)
/IOT_176: J1.118, U1.A16 (IOT_176)
/IOT_177: J1.116, U1.A15 (IOT_177)
/IOT_178: J1.114, U1.B13 (IOT_178)
/IOT_179: J1.53, U1.E10 (IOT_179)
/IOT_180: J1.52, U1.C11 (IOT_180)
/IOT_181: J1.51, U1.D11 (IOT_181)
/IOT_182: J1.113, U1.B12 (IOT_182)
/IOT_183: J1.108, U1.B10 (IOT_183)
/IOT_184: J1.112, U1.B11 (IOT_184)
/IOT_185: J1.48, U1.C10 (IOT_185)
/IOT_186: J1.107, U1.A10 (IOT_186)
/IOT_187: J1.111, U1.A11 (IOT_187)
/IOT_190: J1.47, U1.D10 (IOT_190)
/IOT_191: J1.46, U1.C9 (IOT_191)
/IOT_192: J1.44, U1.E9 (IOT_192)
/IOT_193: J1.45, U1.D9 (IOT_193)
/IOT_194: J1.105, U1.A9 (IOT_194)
/IOT_196: J1.94, U1.F9 (IOT_196)
/IOT_197: J1.42, U1.C8 (IOT_197_GBIN1)
/IOT_198: J1.96, U1.F7 (IOT_198_GBIN0)
/IOT_199: J1.106, U1.B9 (IOT_199)
/IOT_200: J1.43, U1.D8 (IOT_200)
/IOT_203: J1.104, U1.B8 (IOT_203)
/IOT_205: J1.102, U1.A7 (IOT_205)
/IOT_206: J1.38, U1.C7 (IOT_206)
/IOT_207: J1.103, U1.B7 (IOT_207)
/IOT_208: J1.101, U1.B6 (IOT_208)
/IOT_209: J1.37, U1.C6 (IOT_209)
/IOT_210: J1.41, U1.D7 (IOT_210)
/IOT_211: J1.98, U1.A6 (IOT_211)
/IOT_212: J1.30, U1.D6 (IOT_212)
/IOT_213: J1.97, U1.A5 (IOT_213)
/IOT_214: J1.36, U1.B5 (IOT_214)
/IOT_215: J1.29, U1.E6 (IOT_215)
/IOT_216: J1.95, U1.B4 (IOT_216)
/IOT_218: J1.92, U1.A2 (IOT_218)
/IOT_219: J1.35, U1.D5 (IOT_219)
/IOT_220: J1.91, U1.A1 (IOT_220)
/IOT_221: J1.27, U1.C5 (IOT_221)
/IOT_222: J1.34, U1.C4 (IOT_222)
/IOT_223: J1.93, U1.B3 (IOT_223)
/IOT_224: J1.32, U1.D4 (IOT_224)
/IOT_225: J1.28, U1.E5 (IOT_225)
/IOT_226: J1.31, U1.D3 (IOT_226)
/IOT_227: J1.33, U1.C3 (IOT_227)
GND: 5V_1.1 (K), C1.2, CDONE1.1 (K), J1.2, J1.12, J1.22, J1.40, J1.50, J1.60, J1.62, J1.72, J1.82, J1.100, J1.110, J1.120, J1.121, J1.122, J1.123, J1.124, J1.125, J1.126, J2.2, J2.12, J2.22, J2.40, J2.50, J2.60, J2.62, J2.72, J2.82, J2.100, J2.110, J2.120, J2.121, J2.122, J2.123, J2.124, J2.125, J2.126, PM2.5, PM2.11, RESET1.1, USR1.1 (K), USR2.1 (K), X1.2 (GND); also elsewhere on the board
unnamed: 5V_1.2 (A), R4.1
unnamed: R5.2, USR1.2 (A)
unnamed: R6.2, USR2.2 (A)
unnamed: R2.1, X1.1 (OE)

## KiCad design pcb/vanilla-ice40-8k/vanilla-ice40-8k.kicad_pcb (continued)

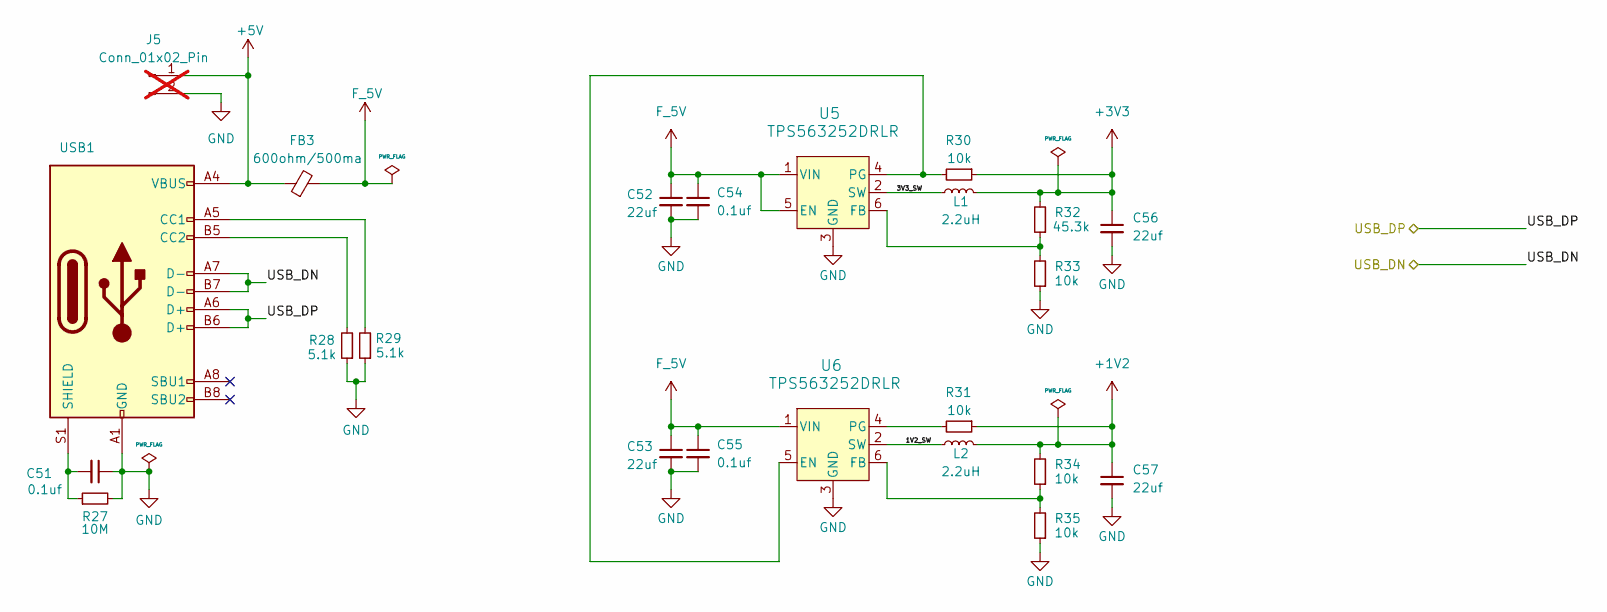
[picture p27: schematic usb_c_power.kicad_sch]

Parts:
C51, C54, C55: 0.1uf; C_0402_1005Metric; LCSC Part # C1525
C52, C53, C56, C57: 22uf; C_0603_1608Metric; LCSC Part # C59461
FB3: 600ohm/500ma; L_0603_1608Metric; LCSC Part # C1002
J5: Conn_01x02_Pin; PinHeader_1x02_P2.54mm_Vertical; not fitted
L1, L2: 2.2uH; L_1008_2520Metric; LCSC Part # C391305
R27: 10M; R_0603_1608Metric; LCSC Part # C7250
R28, R29: 5.1k; R_0603_1608Metric; LCSC Part # C23186
R30, R31, R33, R34, R35: 10k; R_0603_1608Metric; LCSC Part # C25804
R32: 45.3k; R_0603_1608Metric; LCSC Part # C23058
U5, U6: TPS563252DRLR; SOT6_DRL_TEX; LCSC Part # C19188399
USB1: USB_C_Receptacle_USB2.0_16P; USB_C_Receptacle_GCT_USB4105-xx-A_16P_TopMnt_Horizontal; LCSC Part # C2686968

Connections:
+1V2: C57.1, L2.2, R31.1, R34.2; also elsewhere on the board
+3V3: C56.1, L1.2, R30.1, R32.2; also elsewhere on the board
+5V: FB3.1, J5.1, USB1.A4 (VBUS), USB1.A9 (VBUS), USB1.B4 (VBUS), USB1.B9 (VBUS); also elsewhere on the board
/USB_DN: USB1.A7 (D-), USB1.B7 (D-); also elsewhere on the board
/USB_DP: USB1.A6 (D+), USB1.B6 (D+); also elsewhere on the board
/usb-c power/1V2_SW: L2.1, U6.2 (SW)
/usb-c power/3V3_SW: L1.1, U5.2 (SW)
F_5V: C52.1, C53.1, C54.1, C55.1, FB3.2, U5.1 (VIN), U5.5 (EN), U6.1 (VIN)
GND: C51.1, C52.2, C53.2, C54.2, C55.2, C56.2, C57.2, J5.2, R27.2, R28.1, R29.1, R33.1, R35.1, U5.3 (GND), U6.3 (GND), USB1.A1 (GND), USB1.A12 (GND), USB1.B1 (GND), USB1.B12 (GND); also elsewhere on the board
unnamed: R32.1, R33.2, U5.6 (FB)
unnamed: R30.2, U5.4 (PG), U6.5 (EN)
unnamed: R34.1, R35.2, U6.6 (FB)
unnamed: R31.2, U6.4 (PG)
unnamed: R29.2, USB1.A5 (CC1)
unnamed: R28.2, USB1.B5 (CC2)
unnamed: C51.2, R27.1, USB1.S1 (SHIELD)


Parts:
C2, C3, C4, C22, C23, C24, C30: 22uf; C_0603_1608Metric; LCSC Part # C59461
C5, C6, C7, C8, C9, C10, C11, C12, C13, C14, C15, C16, C17, C18, C19, C20, C21, C25, C26, C27, C28, C29, C31, C32, C33, C34: 0.1uf; C_0402_1005Metric_no_courtyard; LCSC Part # C1525
D1: 1N4148WSF-7; D_SOD-323F; LCSC Part # C119617
R7, R8: 100; R_0603_1608Metric; LCSC Part # C22775
U1: ICE40HX8K-CT256; BGA256C80P16X16_1400X1400X170; PART_REV 3.4

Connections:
+1V2: C2.1, C5.1, C8.1, C13.1, C16.1, C17.1, C19.1, R7.1, R8.1, U1.A14 (VCC), U1.F6 (VCC), U1.F10 (VCC), U1.K6 (VCC), U1.K10 (VCC), U1.L2 (VCC); also elsewhere on the board
+3V3: C3.1, C4.1, C6.1, C7.1, C9.1, C10.1, C11.1, C12.1, C14.1, C15.1, C18.1, C22.1, C23.1, C25.1, C26.1, C28.1, C29.1, C31.1, C32.1, C33.1, C34.1, D1.2 (A), U1.A3 (VCCIO_0), U1.A8 (VCCIO_0), U1.A13 (VCCIO_0), U1.C15 (VCCIO_1), U1.E1 (VCCIO_3), U1.F8 (VCCIO_0), U1.G6 (VCCIO_3), U1.H10 (VCCIO_1), U1.H15 (VCCIO_1), U1.J6 (VCCIO_3), U1.K8 (VCCIO_2), U1.N1 (VCCIO_3), U1.N13 (VCC_SPI), U1.N15 (VCCIO_1), U1.P3 (VCCIO_2), U1.R8 (VCCIO_2), U1.R13 (VCCIO_2); also elsewhere on the board
/hx8k power/GNDPLL0: C21.2, C24.2, U1.N8 (GNDPLL0)
/hx8k power/GNDPLL1: C27.2, C30.2, U1.E7 (GNDPLL1)
GND: C2.2, C3.2, C4.2, C5.2, C6.2, C7.2, C8.2, C9.2, C10.2, C11.2, C12.2, C13.2, C14.2, C15.2, C16.2, C17.2, C18.2, C19.2, C20.2, C22.2, C23.2, C25.2, C26.2, C28.2, C29.2, C31.2, C32.2, C33.2, C34.2, U1.A4 (GND), U1.A12 (GND), U1.E15 (GND), U1.G7 (GND), U1.G8 (GND), U1.G9 (GND), U1.H7 (GND), U1.H8 (GND), U1.H9 (GND), U1.J7 (GND), U1.J8 (GND), U1.J9 (GND), U1.K2 (GND), U1.K7 (GND), U1.L15 (GND), U1.R7 (GND), U1.T4 (GND), U1.T12 (GND); also elsewhere on the board
unnamed: C20.1, D1.1 (K), U1.E12 (VPP_2V5)
unnamed: C21.1, C24.1, R7.2, U1.L8 (VCCPLL0)
unnamed: C27.1, C30.1, R8.2, U1.E8 (VCCPLL1)


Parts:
C35, C37, C40, C43, C44, C45, C46, C47, C48, C49: 0.1uf; C_0402_1005Metric; LCSC Part # C1525
C36, C41, C42, C50: 22uf; C_0603_1608Metric; LCSC Part # C59461
C38, C39: 27pf; C_0402_1005Metric; LCSC Part # C1555
FB1, FB2: 600ohm/500ma; L_0603_1608Metric; LCSC Part # C1002
J3: Conn_01x06_Pin; PinHeader_1x06_P2.54mm_Vertical; not fitted
J4: Conn_01x02_Pin; PinHeader_1x02_P2.54mm_Vertical; not fitted
R9, R10, R12, R23, R24, R25, R26: 10k; R_0603_1608Metric; LCSC Part # C25804
R11, R14: 2.2k; R_0603_1608Metric; LCSC Part # C4190
R13: 12k; R_0603_1608Metric; LCSC Part # C22790
R15, R16, R17, R18, R19, R20, R21, R22: 0; R_0603_1608Metric; LCSC Part # C21189
U2: 93LCxxBxxOT; SOT-23-6; LCSC Part # C190271
U3: FT2232HL; LQFP-64_10x10mm_P0.5mm; LCSC Part # C27882
U4: W25X40CLSN; SOIC-8_3.9x4.9mm_P1.27mm; LCSC Part # C19617
Y1: 12Mhz/18pf; Crystal_SMD_3225-4Pin_3.2x2.5mm; LCSC Part # C390764

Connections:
+3V3: C35.1, C40.1, C45.1, C46.1, C47.1, C48.1, C49.1, C50.1, FB1.1, FB2.1, J3.6, R9.1, R10.1, R12.1, R14.1, R23.1, R24.1, R25.1, R26.1, U2.6 (VCC), U3.20 (VCCIO), U3.31 (VCCIO), U3.42 (VCCIO), U3.50 (VREGIN), U3.56 (VCCIO), U4.8 (VCC); also elsewhere on the board
/CDONE: R19.2; also elsewhere on the board
/CRESET#: R20.2; also elsewhere on the board
/IOB_105_SDO: J3.2, R17.2, U4.2 (DO(IO1)); also elsewhere on the board
/IOB_106_SDI: J3.1, R16.2, U4.5 (DI(IO0)); also elsewhere on the board
/IOB_107_SCK: J3.3, R15.2, R24.2, U4.6 (SCK); also elsewhere on the board
/IOB_108_SS: J3.4, R18.2, R23.2, U4.1 (~CS); also elsewhere on the board
/USB_DN: U3.7 (DM); also elsewhere on the board
/USB_DP: U3.8 (DP); also elsewhere on the board
/sram programmer/FT_VCORE: C36.1, C37.1, U3.12 (VCORE), U3.37 (VCORE), U3.49 (VREGOUT), U3.64 (VCORE)
/sram programmer/RESET#: J4.1, R14.2, U3.14 (~RESET)
/sram programmer/UART_RX: R22.2
/sram programmer/UART_TX: R21.2
GND: C35.2, C36.2, C37.2, C38.2, C39.2, C40.2, C41.2, C42.2, C43.2, C44.2, C45.2, C46.2, C47.2, C48.2, C49.2, C50.2, J3.5, J4.2, R13.1, U2.2 (GND), U3.1 (GND), U3.5 (GND), U3.10 (AGND), U3.11 (GND), U3.13 (TEST), U3.15 (GND), U3.25 (GND), U3.35 (GND), U3.47 (GND), U3.51 (GND), U4.4 (GND), Y1.2, Y1.4; also elsewhere on the board
unnamed: R10.2, U2.4 (CLK), U3.62 (EECLK)
unnamed: R12.2, U2.5 (CS), U3.63 (EECS)
unnamed: R11.2, U2.3 (DI), U3.61 (EEDATA)
unnamed: R9.2, R11.1, U2.1 (DO)
unnamed: R15.1, U3.16 (ADBUS0)
unnamed: R16.1, U3.17 (ADBUS1)
unnamed: R17.1, U3.18 (ADBUS2)
unnamed: R18.1, U3.21 (ADBUS4)
unnamed: R19.1, U3.23 (ADBUS6)
unnamed: R20.1, U3.24 (ADBUS7)
unnamed: R21.1, U3.38 (BDBUS0)
unnamed: R22.1, U3.39 (BDBUS1)
unnamed: C38.1, U3.2 (OSCI), Y1.3
unnamed: C39.1, U3.3 (OSCO), Y1.1
unnamed: R13.2, U3.6 (REF)
unnamed: C42.1, C44.1, FB2.2, U3.4 (VPHY)
unnamed: C41.1, C43.1, FB1.2, U3.9 (VPLL)
unnamed: R26.2, U4.7 (~HOLD)
unnamed: R25.2, U4.3 (~WP)



Board: 6 copper layers, 100.0 x 62.0 mm, 118 parts (68 on the bottom side), 149 nets.

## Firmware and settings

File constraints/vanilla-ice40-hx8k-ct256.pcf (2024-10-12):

set_io CLK J3
set_io LED1 H11
set_io LED2 G12
set_io UART_RX J12
set_io UART_TX J11

set_io L_A_01 R1
set_io L_A_02 P1
set_io L_A_03 M2
set_io L_A_04 L1
set_io L_A_05 P2
set_io L_A_06 N2
set_io L_A_07 M1
set_io L_A_08 K1

set_io L_A[0] R1
set_io L_A[1] P1
set_io L_A[2] M2
set_io L_A[3] L1
set_io L_A[4] P2
set_io L_A[5] N2
set_io L_A[6] M1
set_io L_A[7] K1

set_io L_B_01 J2
set_io L_B_02 H2
set_io L_B_03 G2
set_io L_B_04 F1
set_io L_B_05 J1
set_io L_B_06 H1
set_io L_B_07 G1
set_io L_B_08 F2

set_io L_B[0] J2
set_io L_B[1] H2
set_io L_B[2] G2
set_io L_B[3] F1
set_io L_B[4] J1
set_io L_B[5] H1
set_io L_B[6] G1
set_io L_B[7] F2

set_io L_C_01 E2
set_io L_C_02 D2
set_io L_C_03 C2
set_io L_C_04 F7
set_io L_C_05 D1
set_io L_C_06 C1
set_io L_C_07 B1
set_io L_C_08 B2

set_io L_C[0] E2
set_io L_C[1] D2
set_io L_C[2] C2
set_io L_C[3] F7
set_io L_C[4] D1
set_io L_C[5] C1
set_io L_C[6] B1
set_io L_C[7] B2

set_io L_D_01 A1
set_io L_D_02 B3
set_io L_D_03 B5
set_io L_D_04 B6
set_io L_D_05 A2
set_io L_D_06 B4
set_io L_D_07 A5
set_io L_D_08 A6

set_io L_D[0] A1
set_io L_D[1] B3
set_io L_D[2] B5
set_io L_D[3] B6
set_io L_D[4] A2
set_io L_D[5] B4
set_io L_D[6] A5
set_io L_D[7] A6

set_io L_E_01 N3
set_io L_E_02 L4
set_io L_E_03 L3
set_io L_E_04 K3
set_io L_E_05 L5
set_io L_E_06 M3
set_io L_E_07 K4
set_io L_E_08 J5

set_io L_E[0] N3
set_io L_E[1] L4
set_io L_E[2] L3
set_io L_E[3] K3
set_io L_E[4] L5
set_io L_E[5] M3
set_io L_E[6] K4
set_io L_E[7] J5

set_io L_F_01 H5
set_io L_F_02 H4
set_io L_F_03 G4
set_io L_F_04 F3
set_io L_F_05 J4
set_io L_F_06 H3
set_io L_F_07 G3
set_io L_F_08 F4

set_io L_F[0] H5
set_io L_F[1] H4
set_io L_F[2] G4
set_io L_F[3] F3
set_io L_F[4] J4
set_io L_F[5] H3
set_io L_F[6] G3
set_io L_F[7] F4

set_io L_G_01 B7
set_io L_G_02 B8
set_io L_G_03 A9
set_io L_G_04 A10
set_io L_G_05 A7
set_io L_G_06 B9
set_io L_G_07 B10
set_io L_G_08 B11

set_io L_G[0] B7
set_io L_G[1] B8
set_io L_G[2] A9
set_io L_G[3] A10
set_io L_G[4] A7
set_io L_G[5] B9
set_io L_G[6] B10
set_io L_G[7] B11

set_io L_H_01 A11
set_io L_H_02 B13
set_io L_H_03 B14
set_io L_H_04 B15
set_io L_H_05 B12
set_io L_H_06 C13
set_io L_H_07 A15
set_io L_H_08 A16

set_io L_H[0] A11
set_io L_H[1] B13
set_io L_H[2] B14
set_io L_H[3] B15
set_io L_H[4] B12
set_io L_H[5] C13
set_io L_H[6] A15
set_io L_H[7] A16

set_io L_I_01 C3
set_io L_I_02 C4
set_io L_I_03 C5
set_io L_I_04 C6
set_io L_I_05 D4
set_io L_I_06 D5
set_io L_I_07 D6
set_io L_I_08 D7

set_io L_I[0] C3
set_io L_I[1] C4
set_io L_I[2] C5
set_io L_I[3] C6
set_io L_I[4] D4
set_io L_I[5] D5
set_io L_I[6] D6
set_io L_I[7] D7

set_io L_J_01 C11
set_io L_J_02 D13
set_io L_J_03 E9
set_io L_J_04 E11
set_io L_J_05 C12
set_io L_J_06 C14
set_io L_J_07 E10
set_io L_J_08 F9

set_io L_J[0] C11
set_io L_J[1] D13
set_io L_J[2] E9
set_io L_J[3] E11
set_io L_J[4] C12
set_io L_J[5] C14
set_io L_J[6] E10
set_io L_J[7] F9

set_io L_K_01 D11
set_io L_K_02 D10
set_io L_K_03 D9
set_io L_K_04 D8
set_io L_K_05 C10
set_io L_K_06 C9
set_io L_K_07 C8
set_io L_K_08 C7

set_io L_K[0] D11
set_io L_K[1] D10
set_io L_K[2] D9
set_io L_K[3] D8
set_io L_K[4] C10
set_io L_K[5] C9
set_io L_K[6] C8
set_io L_K[7] C7

set_io L_L_01 D3
set_io L_L_02 E5
set_io L_L_03 G5
set_io L_L_04 E3
set_io L_L_05 E6
set_io L_L_06 F5
set_io L_L_07 E4
set_io L_L_08 H6

set_io L_L[0] D3
set_io L_L[1] E5
set_io L_L[2] G5
set_io L_L[3] E3
set_io L_L[4] E6
set_io L_L[5] F5
set_io L_L[6] E4
set_io L_L[7] H6

set_io L_PMOD_A[0] R1
set_io L_PMOD_A[1] P1
set_io L_PMOD_A[2] M2
set_io L_PMOD_A[3] L1
set_io L_PMOD_A[4] P2
set_io L_PMOD_A[5] N2
set_io L_PMOD_A[6] M1
set_io L_PMOD_A[7] K1

set_io L_PMOD_B[0] J2
set_io L_PMOD_B[1] H2
set_io L_PMOD_B[2] G2
set_io L_PMOD_B[3] F1
set_io L_PMOD_B[4] J1
set_io L_PMOD_B[5] H1
set_io L_PMOD_B[6] G1
set_io L_PMOD_B[7] F2

set_io L_PMOD_C[0] E2
set_io L_PMOD_C[1] D2
set_io L_PMOD_C[2] C2
set_io L_PMOD_C[3] F7
set_io L_PMOD_C[4] D1
set_io L_PMOD_C[5] C1
set_io L_PMOD_C[6] B1
set_io L_PMOD_C[7] B2

set_io L_PMOD_D[0] A1
set_io L_PMOD_D[1] B3
set_io L_PMOD_D[2] B5
set_io L_PMOD_D[3] B6
set_io L_PMOD_D[4] A2
set_io L_PMOD_D[5] B4
set_io L_PMOD_D[6] A5
set_io L_PMOD_D[7] A6

set_io L_PMOD_E[0] N3
set_io L_PMOD_E[1] L4
set_io L_PMOD_E[2] L3
set_io L_PMOD_E[3] K3
set_io L_PMOD_E[4] L5
set_io L_PMOD_E[5] M3
set_io L_PMOD_E[6] K4
set_io L_PMOD_E[7] J5

set_io L_PMOD_F[0] H5
set_io L_PMOD_F[1] H4
set_io L_PMOD_F[2] G4
set_io L_PMOD_F[3] F3
set_io L_PMOD_F[4] J4
set_io L_PMOD_F[5] H3
set_io L_PMOD_F[6] G3
set_io L_PMOD_F[7] F4

set_io L_PMOD_G[0] B7
set_io L_PMOD_G[1] B8
set_io L_PMOD_G[2] A9
set_io L_PMOD_G[3] A10
set_io L_PMOD_G[4] A7
set_io L_PMOD_G[5] B9
set_io L_PMOD_G[6] B10
set_io L_PMOD_G[7] B11

set_io L_PMOD_H[0] A11
set_io L_PMOD_H[1] B13
set_io L_PMOD_H[2] B14
set_io L_PMOD_H[3] B15
set_io L_PMOD_H[4] B12
set_io L_PMOD_H[5] C13
set_io L_PMOD_H[6] A15
set_io L_PMOD_H[7] A16
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

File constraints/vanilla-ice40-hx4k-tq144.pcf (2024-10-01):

set_io CLK 21
set_io LED1 1
set_io LED2 2
set_io UART_RX 3
set_io UART_TX 4

set_io R_A_01 112
set_io R_A_02 107
set_io R_A_03 105
set_io R_A_04 102
set_io R_A_05 110
set_io R_A_06 106
set_io R_A_07 104
set_io R_A_08 101

set_io R_A[0] 112
set_io R_A[1] 107
set_io R_A[2] 105
set_io R_A[3] 102
set_io R_A[4] 110
set_io R_A[5] 106
set_io R_A[6] 104
set_io R_A[7] 101

set_io R_B_01 99
set_io R_B_02 97
set_io R_B_03 95
set_io R_B_04 93
set_io R_B_05 98
set_io R_B_06 96
set_io R_B_07 94
set_io R_B_08 91

set_io R_B[0] 99
set_io R_B[1] 97
set_io R_B[2] 95
set_io R_B[3] 93
set_io R_B[4] 98
set_io R_B[5] 96
set_io R_B[6] 94
set_io R_B[7] 91

set_io R_C_01 90
set_io R_C_02 87
set_io R_C_03 84
set_io R_C_04 82
set_io R_C_05 88
set_io R_C_06 85
set_io R_C_07 83
set_io R_C_08 81

set_io R_C[0] 90
set_io R_C[1] 87
set_io R_C[2] 84
set_io R_C[3] 82
set_io R_C[4] 88
set_io R_C[5] 85
set_io R_C[6] 83
set_io R_C[7] 81

set_io R_D_01 80
set_io R_D_02 78
set_io R_D_03 75
set_io R_D_04 73
set_io R_D_05 79
set_io R_D_06 76
set_io R_D_07 74
set_io R_D_08 62

set_io R_D[0] 80
set_io R_D[1] 78
set_io R_D[2] 75
set_io R_D[3] 73
set_io R_D[4] 79
set_io R_D[5] 76
set_io R_D[6] 74
set_io R_D[7] 62

set_io R_E_01 134
set_io R_E_02 129
set_io R_E_03 125
set_io R_E_04 122
set_io R_E_05 130
set_io R_E_06 128
set_io R_E_07 124
set_io R_E_08 121

set_io R_E[0] 134
set_io R_E[1] 129
set_io R_E[2] 125
set_io R_E[3] 122
set_io R_E[4] 130
set_io R_E[5] 128
set_io R_E[6] 124
set_io R_E[7] 121

set_io R_F_01 120
set_io R_F_02 118
set_io R_F_03 116
set_io R_F_04 114
set_io R_F_05 119
set_io R_F_06 117
set_io R_F_07 115
set_io R_F_08 113

set_io R_F[0] 120
set_io R_F[1] 118
set_io R_F[2] 116
set_io R_F[3] 114
set_io R_F[4] 119
set_io R_F[5] 117
set_io R_F[6] 115
set_io R_F[7] 113

set_io R_G_01 61
set_io R_G_02 56
set_io R_G_03 52
set_io R_G_04 48
set_io R_G_05 60
set_io R_G_06 55
set_io R_G_07 49
set_io R_G_08 47

set_io R_G[0] 61
set_io R_G[1] 56
set_io R_G[2] 52
set_io R_G[3] 48
set_io R_G[4] 60
set_io R_G[5] 55
set_io R_G[6] 49
set_io R_G[7] 47

set_io R_H_01 45
set_io R_H_02 43
set_io R_H_03 41
set_io R_H_04 38
set_io R_H_05 44
set_io R_H_06 42
set_io R_H_07 39
set_io R_H_08 37

set_io R_H[0] 45
set_io R_H[1] 43
set_io R_H[2] 41
set_io R_H[3] 38
set_io R_H[4] 44
set_io R_H[5] 42
set_io R_H[6] 39
set_io R_H[7] 37

set_io R_I_01 144
set_io R_I_02 8
set_io R_I_03 10
set_io R_I_04 12
set_io R_I_05 7
set_io R_I_06 9
set_io R_I_07 11
set_io R_I_08 15

set_io R_I[0] 144
set_io R_I[1] 8
set_io R_I[2] 10
set_io R_I[3] 12
set_io R_I[4] 7
set_io R_I[5] 9
set_io R_I[6] 11
set_io R_I[7] 15

set_io R_J_01 25
set_io R_J_02 28
set_io R_J_03 31
set_io R_J_04 33
set_io R_J_05 26
set_io R_J_06 29
set_io R_J_07 32
set_io R_J_08 34

set_io R_J[0] 25
set_io R_J[1] 28
set_io R_J[2] 31
set_io R_J[3] 33
set_io R_J[4] 26
set_io R_J[5] 29
set_io R_J[6] 32
set_io R_J[7] 34

set_io R_K_01 24
set_io R_K_02 22
set_io R_K_03 19
set_io R_K_04 17
set_io R_K_05 23
set_io R_K_06 20
set_io R_K_07 18
set_io R_K_08 16

set_io R_K[0] 24
set_io R_K[1] 22
set_io R_K[2] 19
set_io R_K[3] 17
set_io R_K[4] 23
set_io R_K[5] 20
set_io R_K[6] 18
set_io R_K[7] 16

set_io R_L_01 143
set_io R_L_02 141
set_io R_L_03 138
set_io R_L_04 136
set_io R_L_05 142
set_io R_L_06 139
set_io R_L_07 137
set_io R_L_08 135

set_io R_L[0] 143
set_io R_L[1] 141
set_io R_L[2] 138
set_io R_L[3] 136
set_io R_L[4] 142
set_io R_L[5] 139
set_io R_L[6] 137
set_io R_L[7] 135

set_io R_PMOD_A[0] 112
set_io R_PMOD_A[1] 107
set_io R_PMOD_A[2] 105
set_io R_PMOD_A[3] 102
set_io R_PMOD_A[4] 110
set_io R_PMOD_A[5] 106
set_io R_PMOD_A[6] 104
set_io R_PMOD_A[7] 101

set_io R_PMOD_B[0] 99
set_io R_PMOD_B[1] 97
set_io R_PMOD_B[2] 95
set_io R_PMOD_B[3] 93
set_io R_PMOD_B[4] 98
set_io R_PMOD_B[5] 96
set_io R_PMOD_B[6] 94
set_io R_PMOD_B[7] 91

set_io R_PMOD_C[0] 90
set_io R_PMOD_C[1] 87
set_io R_PMOD_C[2] 84
set_io R_PMOD_C[3] 82
set_io R_PMOD_C[4] 88
set_io R_PMOD_C[5] 85
set_io R_PMOD_C[6] 83
set_io R_PMOD_C[7] 81

set_io R_PMOD_D[0] 80
set_io R_PMOD_D[1] 78
set_io R_PMOD_D[2] 75
set_io R_PMOD_D[3] 73
set_io R_PMOD_D[4] 79
set_io R_PMOD_D[5] 76
set_io R_PMOD_D[6] 74
set_io R_PMOD_D[7] 62

set_io R_PMOD_E[0] 134
set_io R_PMOD_E[1] 129
set_io R_PMOD_E[2] 125
set_io R_PMOD_E[3] 122
set_io R_PMOD_E[4] 130
set_io R_PMOD_E[5] 128
set_io R_PMOD_E[6] 124
set_io R_PMOD_E[7] 121

set_io R_PMOD_F[0] 120
set_io R_PMOD_F[1] 118
set_io R_PMOD_F[2] 116
set_io R_PMOD_F[3] 114
set_io R_PMOD_F[4] 119
set_io R_PMOD_F[5] 117
set_io R_PMOD_F[6] 115
set_io R_PMOD_F[7] 113

set_io R_PMOD_G[0] 61
set_io R_PMOD_G[1] 56
set_io R_PMOD_G[2] 52
set_io R_PMOD_G[3] 48
set_io R_PMOD_G[4] 60
set_io R_PMOD_G[5] 55
set_io R_PMOD_G[6] 49
set_io R_PMOD_G[7] 47

set_io R_PMOD_H[0] 45
set_io R_PMOD_H[1] 43
set_io R_PMOD_H[2] 41
set_io R_PMOD_H[3] 38
set_io R_PMOD_H[4] 44
set_io R_PMOD_H[5] 42
set_io R_PMOD_H[6] 39
set_io R_PMOD_H[7] 37
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

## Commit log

2024-05-20 initial checkin - wip
    [FX18-60S-0.8SH--3DModel-STEP-1.STEP, SMD_2MSB4SI_YXC.step, SOD323F_DIO.step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]
2024-05-20 rough pcb placement done
    [vanillaice40.kicad_pcb, vanillaice40.kicad_sch]
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2024-05-21 FT2232HL - clock and eeprom routing
    [vanillaice40.kicad_pcb]
2024-05-21 flash routed to ft2232hl
    [vanillaice40.kicad_pcb]
2024-05-21 top/right/bottom ice40 io routing
    [vanillaice40.kicad_pcb]
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2024-05-21 io moved to lower diff
    [vanillaice40.kicad_pcb, vanillaice40.kicad_sch]
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2024-05-21 start of 3rd reroute
    [vanillaice40.kicad_pcb, vanillaice40.kicad_sch]
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2024-05-22 connector drc fixes
    [vanillaice40.kicad_pcb]
2024-05-22 drc fixes
    [vanillaice40.kicad_pcb]
2024-05-22 non silkscreen drc fixed
    [vanillaice40.kicad_pcb]
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2024-05-22 silkscreen fixes
    [vanillaice40.kicad_pcb]
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2024-05-23 add flash spi header
    [vanillaice40.kicad_pcb, vanillaice40.kicad_sch]
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2024-05-23 add fab toolkit and setup
    [vanillaice40.kicad_pcb, vanillaice40.kicad_sch]
2024-05-23 starting to populate parts
    [vanillaice40.kicad_pcb, vanillaice40.kicad_sch]
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2024-05-23 start of the flip
    [vanillaice40.kicad_pcb]
2024-05-23 bottom jumper 0ohms flipped
    [vanillaice40.kicad_pcb]
2024-05-23 middle jumpers flipped
    [vanillaice40.kicad_pcb]
2024-05-23 all parts on top layer
    [vanillaice40.kicad_pcb]
2024-05-23 fixed usb part #
    [vanillaice40.kicad_pcb, vanillaice40.kicad_sch]
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2024-05-23 pcb -> schematic footprint update
    [vanillaice40.kicad_sch]
2024-05-23 ensure all gnd pads have a via
    [vanillaice40.kicad_pcb]
2024-05-23 silkscreen and visual improvements
    [vanillaice40.kicad_pcb]
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2024-05-24 start of jclpcb pos fixes
    [vanillaice40.kicad_pcb, vanillaice40.kicad_sch]
2024-05-24 all parts jlcpcb pos/rotated
    [vanillaice40.kicad_pcb, vanillaice40.kicad_sch]
2024-05-25 corrected usb diff pair spacing to 8mils
    [vanillaice40.kicad_pcb]
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2024-05-31 move models to pcb dir
    [FX18-60S-0.8SH--3DModel-STEP-1.STEP, SMD_2MSB4SI_YXC.step, SOD323F_DIO.step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]
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2024-05-31 pmod breakout basic layout
    [breakout-pmod.kicad_pcb, breakout-pmod.kicad_sch]
2024-05-31 copy board settings for breakout
    [breakout-pmod.kicad_pcb, breakout-pmod.kicad_sch]
2024-05-31 fix 1 off error in fx18 pin layout
    [vanilla-ice40.kicad_pcb, vanilla-ice40.kicad_sch]
2024-06-01 redo fx18 breakout layout
    [breakout-pmod.kicad_pcb, breakout-pmod.kicad_sch]
2024-06-01 breakout power and ground
    [breakout-pmod.kicad_pcb, breakout-pmod.kicad_sch]
2024-06-01 wip - pmod signals on breakout
    [breakout-pmod.kicad_pcb]
2024-06-01 ugly first draft of pmod routing
    [breakout-pmod.kicad_pcb, breakout-pmod.kicad_sch]
2024-06-01 wip pmod signal cleanup
    [breakout-pmod.kicad_pcb, breakout-pmod.kicad_sch]
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2024-06-02 remove unused pmod symbol
    [breakout-pmod.kicad_pcb, breakout-pmod.kicad_sch]
2024-06-02 [pmod] add digikey part#
    [breakout-pmod.kicad_pcb, breakout-pmod.kicad_sch, vanilla-ice40.kicad_pcb]
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2024-06-23 [pmod] fix order of ef and gh pmod
    [breakout-pmod.kicad_pcb, breakout-pmod.kicad_sch]
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2024-06-23 [vga] fix h/v sync wire
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2024-06-24 [uart] add tb - but still broken
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2024-06-24 [makefile] fix vga and uart srcs
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2024-06-24 [pins] add (correct) uart tx/rx pins
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2024-06-24 [uart] add reset_i
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2024-06-24 [uart] start of hello fifo - not working
2024-06-25 [uart] fix uart fifo hello
2024-06-26 [solder_chk] move to a branch and deleted from main
    I think this might have been doomed to not work from
    the start. It's not natural for the tb to try to
    drive changes that shouldn't be happening, as they
    really don't want you assigning to outputs, etc.
    And, I haven't fully worked out if the optimizer will
    get in the way.. and finally, the ice40 has no pulldown
    resistors, complicating things. Maybe I'll revisit, but
    for now, at these low volumes, I'll just use a visual led
    test with the pmod breakout board.
2024-06-26 [pmod] fix order of CD pmod
    [breakout-pmod.kicad_pcb, breakout-pmod.kicad_sch]
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2024-06-26 [pmod] fix order of AB pmod
    [breakout-pmod.kicad_pcb, breakout-pmod.kicad_sch]
2024-06-26 [pmod] fix order of BA pmod
    [breakout-pmod.kicad_pcb, breakout-pmod.kicad_sch]
2024-06-26 [pmod] fix order of DC pmod
    [breakout-pmod.kicad_pcb, breakout-pmod.kicad_sch]
2024-06-26 [pmod] fix order of IJ pmod
    [breakout-pmod.kicad_pcb, breakout-pmod.kicad_sch]
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2024-06-26 [pmod] fix order of KL pmod
    [breakout-pmod.kicad_pcb, breakout-pmod.kicad_sch]
2024-06-26 [pmod] fix order of HG pmod
    [breakout-pmod.kicad_pcb, breakout-pmod.kicad_sch]
2024-06-26 [pmod] fix order of LK pmod
    [breakout-pmod.kicad_pcb, breakout-pmod.kicad_sch]
2024-06-27 [pmod] fix order of FE pmod
    Note: this is actually wired backwards on the PCB
    and probably won't mirror correctly.
    [breakout-pmod.kicad_pcb, breakout-pmod.kicad_sch]
2024-06-27 [pmod] fix order of JI pmod
    [breakout-pmod.kicad_pcb, breakout-pmod.kicad_sch]
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2024-06-27 [sram] update with correct nets labels
    [breakout-sram.kicad_pcb, breakout-sram.kicad_sch]
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2024-07-24 [pcb] fix some absolute paths that snuck in
    [breakout-tri-sram.kicad_pcb, vanilla-ice40-8k.kicad_pcb]
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2024-07-25 [pcb][hx8k] IOT and IOL done
    deleted pmods to make room
    [vanilla-ice40-8k.kicad_pcb, vanilla-ice40-8k.kicad_sch]
2024-07-31 [pcb][3xsram] fix latch part number
    [vga_addr_buffers.kicad_sch]
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2024-08-01 [pcb][hx8k] top silkscreen fixes
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2024-08-01 [pcb][hx8k] added mounting holes
    also changed ftdi disable to an unpopulated resistor
    [sram_programmer.kicad_sch, vanilla-ice40-8k.kicad_sch]
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2024-08-03 [pcb][pmod] fix __ to _ typo
    [breakout-pmod.kicad_pcb, breakout-pmod.kicad_sch]
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2024-08-07 [sram] delete old version to start over
    The controller was fundamentally flawed in that it
    wasn't disabling we while changing data and addressees.
    The test will need to be updated, and it had a couple of
    wtf bugs. It will be reintroduced with tests of each part
    along the way, making it clearer that it's operating
    correctly.
2024-08-13 [scripts] fix left side pin gen
2024-08-13 [scripts] fix hx8k pin assignments
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2024-08-13 [pcb][hx8k] fix spi miso/mosi
    [vanilla-ice40-8k.kicad_sch]
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2024-08-15 [pcb][tri-sram] delete tri-sram
    This was a board for a project, but I went in a different
    direction by moving to the hx8k instead of needing all
    these external muxes.
    [a2d_buffers.kicad_sch, blanker.kicad_sch, blanker_data_buffers.kicad_sch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]
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2024-09-15 [adc][pcb] initial op amp circuit with spice simulation
    [breakout-adc.kicad_pcb, breakout-adc.kicad_sch]
2024-09-15 [adc][pcb] X and Y op amp circuits with comments
    [breakout-adc.kicad_sch]
2024-09-16 [adc][pcb] move x/y diff pairs to hierarchical sheet
    [breakout-adc.kicad_sch, xy_diff_pairs.kicad_sch]
2024-09-17 [hx8k][pcb] correct fb rating to 1.5A
    [usb_c_power.kicad_sch]
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2024-09-17 [adc][pcb] RGB and test points added
    Ready for footprints and pcb layout.
    [adc.kicad_sch, breakout-adc.kicad_sch]
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2024-09-17 [adc][pcb] fix ESD diode and jumper ERC errors
    [adc.kicad_sch, breakout-adc.kicad_sch]
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2024-09-18 [adc][pcb] initial layout of X input op amp
    [adc.kicad_sch, breakout-adc.kicad_pcb, breakout-adc.kicad_sch]
2024-09-18 [adc][pcb] initial layout of Y input op amp
    [breakout-adc.kicad_pcb]
2024-09-18 [adc][pcb] initial start of place and route for ADC
    [breakout-adc.kicad_pcb, breakout-adc.kicad_sch]
2024-09-18 [adc][pcb] switch to R arrays and place buffers
    [adc.kicad_sch, breakout-adc.kicad_pcb]
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2024-09-19 [adc][pcb] passives around adc placed and routed
    Had to slightly redo the power passives to squeeze in
    the passives for the reference pins. Digital out
    arrays moved out of the way and need to be redone.
    [adc.kicad_sch, breakout-adc.kicad_pcb]
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2024-09-19 [adc][pcb] redo of upper op amp
    This also includes additional p&r of all components.
    They are all in the pcb boundary now. This rev also
    gives up on being fully single sided. See the layout.md
    notes.
    Lower op amp needs still needs to be placed and routed
    like the upper one.
    [adc.kicad_sch, breakout-adc.kicad_pcb, breakout-adc.kicad_sch]
2024-09-19 [adc][pcb] cleanup upper op amp silks pre copy
    [breakout-adc.kicad_pcb]
2024-09-19 [adc][pcb] redo lower op amp to match the upper
    [breakout-adc.kicad_pcb]
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2024-09-20 [adc][pcb] adc gnd routing (special DRGND handling)
    Note the potentially weird/wrong DRGND routing documented
    in layout.md
    [breakout-adc.kicad_pcb]
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2024-09-20 [adc][pcb] flip flop inputs routed
    [adc.kicad_sch, breakout-adc.kicad_pcb]
2024-09-20 [adc][pcb] update todo with fixes and new todos
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2024-09-20 [adc][pcb] oscillator pwr touch ups
    give a bit more space to solder the cap, and
    add a gnd via nearby the gnd pin
    [breakout-adc.kicad_pcb]
2024-09-20 [adc][pcb] add colored keystone tp fp and models
    Note: these need to have their footprints and models fixed
    as they get used. I only did the ones on this board, even
    though I downloaded and committed all the colors.
    [5000.step, 5001.step, 5002.step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]
2024-09-20 [adc][pcb] move the 3v3 and gnd tp to the edge
    This will (probably) allow for grabbers to connect
    to the through holes even if the tp isn't soldered in.
    [breakout-adc.kicad_pcb, breakout-adc.kicad_sch]
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2024-09-20 [pcb] prep work for FX18-120P footprint fix
    [breakout-adc.kicad_sch, breakout-passthrough.kicad_pcb, breakout-passthrough.kicad_sch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]
2024-09-20 [pcb] add FX18-120P footprint and update pcbs
    and a few adc fixes, including a key resistor fix
    (the op amp for Y had a copy paste error from X
    on the positive Rg)
    [adc.kicad_sch, breakout-adc.kicad_pcb, breakout-adc.kicad_sch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]
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2024-09-20 [adc][pcb] fully routed
    needs some return trace cleanup, return path checks,
    gnd/power plane touchups, and some drc fixes/tweaks.
    [adc.kicad_sch, breakout-adc.kicad_pcb, breakout-adc.kicad_sch]
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2024-09-21 [adc][pcb] relink footprints to fix drc issue
    [adc.kicad_sch, breakout-adc.kicad_pcb, breakout-adc.kicad_sch]
2024-09-21 [adc][pcb] add pin 1 marker to esd diodes
    [breakout-adc.kicad_pcb]
2024-09-21 [adc][pcb] add pin 1 marker to adc and clk fanout
    [breakout-adc.kicad_pcb]
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2024-09-21 [adc][pcb] replace deleted Y hdr silks
    [breakout-adc.kicad_pcb]
2024-09-21 [adc][pcb] clear adc simulator flag
    also start adding part numbers
    [adc.kicad_sch, breakout-adc.kicad_sch]
2024-09-21 [adc][pcb] add remaining part numbers
    missing test points for lcsc, but otherwise done
    [adc.kicad_sch, breakout-adc.kicad_pcb, breakout-adc.kicad_sch]
2024-09-21 [adc][pcb] fix digikey part for ESD protection
    [breakout-adc.kicad_pcb, breakout-adc.kicad_sch]
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2024-10-01 [adc][pcb] fix digikey part num for 0.01uf cap
    [adc.kicad_sch, breakout-adc.kicad_pcb]
2024-10-01 [adc][pcb] add x/y vcm test points
    also fixed some drc issues that somehow snuck in,
    specifically, the esd diodes weren't correctly linked
    to their footprint, despite the footprint being physically
    correct on the pcb
    [breakout-adc.kicad_pcb, breakout-adc.kicad_sch]
2024-10-01 [adc][pcb] add x1 pin 1 marker
    note: this was not done correctly, but a todo was left
    in place to fix it.
    [breakout-adc.kicad_pcb]
2024-10-01 [adc][pcb] remove note about resistors near the dcf header
    These were placed this way to avoid weird jogs of the vcm
    line. They aren't such a pain that it's worth messing with
    vcm traces.
2024-10-01 [adc][pcb] fix output buffer schematic and routing
    [adc.kicad_sch, breakout-adc.kicad_pcb, breakout-adc.kicad_sch]
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2024-10-01 [adc][pcb] fix digikey part for 0.01uf cap
    [adc.kicad_sch]
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2024-10-01 [adc][pcb] document bodge wires
    [breakout-adc.kicad_pcb, breakout-adc.kicad_sch]
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2024-10-12 [pins][hx8k] fix L_H pin mapping
    [vanilla-ice40-hx8k-ct256.pcf]
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2024-10-17 [vga_sram] dbl buf top fixes
    * Fix reset like in the non-dbl buf version.
    * Activate the 2x2 axi switch when pattern gen is done to turn
    the sram over to the output side.
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2024-10-19 [verilog] switch to sync reset
2024-10-19 [sram_tester] fixed timing issue
    For some reason this started happening when we switched to sync
    resets.
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2024-11-02 [sv] replace wire/reg with logic
    [axi_2x2_tb.sv, axi_sram_controller_tb.sv, cdc_fifo_mem_tb.sv]
2024-11-06 [pcf] remove -nowarn
    It is not compatible with icecube2
    [vanilla-ice40-hx4k-tq144.pcf, vanilla-ice40-hx8k-ct256.pcf]
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2024-11-08 [adc] track frame for pixels
    I think this actually might be on the wrong track for how to do persistence,
    but let's snapshot the progress, just in case.
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2024-11-12 [axi] unify reset signal name
    [axi_2x2_tb.sv]
2024-11-15 [fixme][axi_3to2] fixme note about wasting half the sub device capacity
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2024-11-22 [adc] revive adc_xy_vga
    The output is glitchy, just like the 3to2 version.
    However, commit 106331ad was not.
2024-11-24 [makefile] print nextpnr command on failure for debugging
2024-11-25 [adc] bump adc cdc addr size. fixes vga glitch
2024-11-25 [vga_3to2] basic blanking
    This is a fairly terrible implementation in that it just clears
    pixels without any sort of fade, but it works as a POC.
    nextprn can no longer find a place/route that meets timing for the
    consumers of this module, e.g. adc 3to2 and gfx demo 3to2, even
    with looking for seeds all the way to 256. icecube2 easily meets
    timing with an fmax of 120mhz.
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
